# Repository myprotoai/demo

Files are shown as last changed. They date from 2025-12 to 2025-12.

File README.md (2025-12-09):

# ProtoAI

**AI-powered platform that transforms hardware sketches into manufacturable products.**

> **🏆 Hackathon Submission**: [Cursor x Anthropic Hackathon Malaysia](https://luma.com/cursor-hack-my) | [View on Devpost](https://devpost.com/software/protoai-c65x9e)

> **📦 Note**: This repository contains **sample outputs** generated by ProtoAI (assembly instructions, 3D models, PCB files, firmware, etc.), not the ProtoAI platform source code itself.

This repository contains **sample assembly instructions** generated by ProtoAI for building a **Wearable Air Quality Pendant**—a compact, battery-powered device that monitors air quality using TVOC detection with color-coded LED feedback and audio alerts.

### Design Variants

- **Circular Variant** (`samples/circular/`) - Original circular design (32.5mm diameter)
- **Teardrop Variant** (`samples/teardrop/`) - Refined teardrop-shaped design

## 📁 Repository Structure

```
protoai/
├── samples/
│   ├── circular/                    # Circular design variant
│   │   ├── README.md               # Project overview
│   │   ├── Assembly-Instructions.md # Step-by-step assembly guide
│   │   ├── Bill-of-Materials.md    # Complete component list
│   │   ├── 3d-models/               # 3D printable enclosure files
│   │   │   ├── pendant-top-circular.stl
│   │   │   └── pendant-bottom-circular.stl
│   │   ├── firmware/                # Arduino firmware code
│   │   │   └── arduino_code.ino
│   │   ├── pcb/                     # PCB design files
│   │   │   ├── pcb_schematic.pdf
│   │   │   └── gerber_files.zip
│   │   └── images/                  # Assembly instruction images
│   │       ├── 01-pcb-assembly/
│   │       ├── 02-component-installation/
│   │       ├── 03-enclosure-assembly/
│   │       ├── 04-testing/
│   │       └── 05-troubleshooting/
│   │
│   └── teardrop/                    # Teardrop design variant
│       ├── README.md
│       ├── Assembly-Instructions.md
│       ├── Bill-of-Materials.md
│       ├── 3d-models/
│       ├── firmware/
│       ├── pcb/
│       └── images/
│
└── walkthrough.mp4                  # Video demonstration
```

## 🚀 Quick Start

Choose a design variant and follow the assembly guide:
- **Circular** (`samples/circular/`) - 32.5mm diameter
- **Teardrop** (`samples/teardrop/`) - Teardrop-shaped design

Each variant includes PCB files, 3D models (STL), BOM, assembly instructions, and firmware.

## 🔧 Key Features

- **Real-time TVOC monitoring** using SGP40 sensor
- **Ultra-low power design** with STM32U083KCU6 microcontroller
- **Intuitive feedback** - Color-coded LEDs and musical alerts
- **Wearable design** - Compact pendant form factor
- **All-day battery life** with efficient power management
- **USB-C charging** capability

## 📊 Air Quality Classifications

| TVOC Level | Status  | LED Color | Audio Alert |
| --- | --- | --- | --- |
| 0-200 | Good | 🟢 Green | Soft tone |
| 201-300 | Warning | 🟡 Yellow | Warning melody |
| 301-500 | Alarm | 🔴 Red | Urgent beeping |
| >500 | Error | 🔴 Flashing Red | Error tone |

## 🛠️ Hardware Requirements

### Main Components
- **STM32U083KCU6** - Ultra-low-power microcontroller
- **SGP40-D-R4** - Professional TVOC air quality sensor
- **MCP73832T** - Li-Po battery charge controller
- **ADP150AUJZ-2.5-R7** - Low-dropout voltage regulator
- **EAST1616RGBA1** - RGB LEDs (4x)
- **PKMCS0909E4000-R1** - Piezoelectric buzzer

### Tools Required
- Soldering iron and solder
- ST-Link V2 programmer (for firmware upload)
- 3D printer (for enclosure)
- Basic electronics tools

## 📚 Documentation

Each variant includes: README, Assembly Instructions, Bill of Materials, PCB schematic (PDF), and Gerber files. See `walkthrough.mp4` for a video demo.

## 📄 License

MIT

## 🙏 Acknowledgments

This project includes sample assembly instructions and designs based on the [Wearable Air Quality Pendant](https://github.com/Circuit-Digest/Wearable-Air-Quality-Pendant) project by [Circuit-Digest](https://github.com/Circuit-Digest).

### Attribution

Portions of this work are based on:
- **Repository**: [Circuit-Digest/Wearable-Air-Quality-Pendant](https://github.com/Circuit-Digest/Wearable-Air-Quality-Pendant)
- **License**: MIT License
- **Copyright**: © Circuit-Digest

The original project is licensed under the MIT License. The MIT License requires that the above copyright notice and this permission notice be included in all copies or substantial portions of the software.

## 🚀 About ProtoAI

ProtoAI transforms hardware sketches into manufacturable products using AI. Generates 2D diagrams, BOMs, assembly instructions, 3D models (STL), PCB files, and firmware.

**Note**: The ProtoAI platform source code is not included in this repository. This repo contains sample outputs (assembly instructions, 3D models, PCB files, firmware) generated by ProtoAI to demonstrate its capabilities.

**Tech Stack**: Next.js 14, Convex, Tailwind CSS, Radix UI, Zustand

**Team**: [Andre Pratama](https://www.linkedin.com/in/andre-pratama27/), [Hafiz Zakiara](https://www.linkedin.com/in/hafizak/), [Jeremy Yee](https://www.linkedin.com/in/jrmyyee/), [Richard Lee](https://www.linkedin.com/in/yaksheng/)

## 🤝 Contributing

Contributions welcome! For questions, see the `Assembly-Instructions.md` and troubleshooting sections in each variant folder.

---

**⭐ If this project helped you, please consider sharing your build!**

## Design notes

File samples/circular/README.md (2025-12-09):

# Wearable Air Quality Pendant 🌬️
## Circular Casing (Original Design)

A compact, battery-powered wearable device that continuously monitors air quality using TVOC detection. Get real-time feedback about your breathing environment through intuitive LED indicators and audio alerts.

## Project Overview

This DIY air quality monitor pendant uses professional-grade sensors to track Total Volatile Organic Compounds (TVOC) in real-time. Perfect for monitoring indoor air quality at home, office, or industrial environments.

### Key Features

- **Real-time TVOC monitoring** using SGP40 sensor
- **Ultra-low power design** with STM32U083KCU6 microcontroller
- **Intuitive feedback** - Color-coded LEDs and musical alerts
- **Wearable design** - Compact 32.5mm diameter circular pendant
- **All-day battery life** with efficient power management
- **Professional accuracy** with industrial-grade sensor

## Air Quality Classifications

| TVOC Level | Status  | LED Color | Audio Alert |
| --- | --- | --- | --- |
| 0-200 | Good | 🟢 Green | Soft tone |
| 201-300 | Warning | 🟡 Yellow | Warning melody |
| 301-500 | Alarm | 🔴 Red | Urgent beeping |
| >500 | Error | 🔴 Flashing Red | Error tone |

## Hardware Components

### Main Components

- **STM32U083KCU6** - Ultra-low-power microcontroller
- **SGP40-D-R4** - Professional TVOC air quality sensor
- **MCP73832T** - Li-Po battery charge controller
- **ADP150AUJZ-2.5-R7** - Low-dropout voltage regulator
- **EAST1616RGBA1** - RGB LEDs (4x)
- **PKMCS0909E4000-R1** - Piezoelectric buzzer

### Power Management

- Li-Po battery charging via USB-C
- Regulated 2.5V supply for stable operation
- Ultra-low power consumption for all-day use

## 📁 What's in This Package

This ZIP file contains everything you need to build the Air Quality Monitoring Necklace Pendant with **circular casing**:

```
circular/
├── README.md                          # This file - project overview
├── Assembly-Instructions.md           # Step-by-step assembly guide (circular design)
├── Bill-of-Materials.md               # Complete component list with part numbers
├── pcb/
│   ├── pcb_schematic.pdf             # PCB schematic diagram
│   └── gerber_files.zip              # Gerber manufacturing files for PCB fabrication
├── 3d-models/
│   ├── pendant-top-circular.stl      # Top enclosure STL for 3D printing
│   └── pendant-bottom-circular.stl   # Bottom enclosure STL for 3D printing
├── firmware/
│   └── arduino_code.ino              # Arduino firmware code
└── images/
    ├── 01-pcb-assembly/               # 20 PCB assembly instruction images
    ├── 02-component-installation/     # 3 component installation images
    ├── 03-enclosure-assembly/         # 11 enclosure assembly images (circular design)
    ├── 04-testing/                    # 8 testing and verification images
    └── 05-troubleshooting/            # 8 troubleshooting guide images
```

## 🚀 Quick Start Guide

### 1. Hardware Assembly

1. **Order PCB**: Use the Gerber files in `pcb/gerber_files.zip` to order your PCB from a fabrication service
2. **3D Print Enclosure**: Use the STL files in `3d-models/` to print the circular top and bottom enclosure halves
3. **Solder Components**: Follow the detailed `Bill-of-Materials.md` and assembly instructions
4. **Assemble**: Follow the step-by-step guide in `Assembly-Instructions.md`

### 2. Software Setup

1. **Install Arduino IDE** (version 1.8.19 or newer)
2. **Add STM32 board support**
3. **Install required libraries**:
   - DFRobot_SGP40
   - PlayRtttl
   - ptScheduler
4. **Upload firmware**: Use the code in `firmware/arduino_code.ino` with ST-Link programmer

## Required Libraries

Add these libraries through Arduino IDE Library Manager:

```cpp
#include <DFRobot_SGP40.h>     // SGP40 sensor communication
#include <PlayRtttl.hpp>       // Musical tone generation
#include <ptScheduler.h>       // Non-blocking task scheduling
```

## Programming the Device

### Hardware Requirements

- **ST-Link V2 programmer** (required for STM32)
- **USB-C cable** for power and charging
- **3.3V power supply** during programming

### Upload Process

1. Connect ST-Link to SWD pins (SWDIO, SWCLK)
2. Select board: "STM32U0 series" in Arduino IDE
3. Select programmer: "STM32CubeProgrammer (SWD)"
4. Upload firmware

## PCB Specifications

- **Dimensions**: 32.5mm diameter (circular)
- **Layers**: 2-layer PCB
- **Thickness**: 1.6mm
- **Components**: SMD (0603/0402 packages)
- **Connector**: USB-C for charging

## 3D Printing Guide

### Print Settings

- **Layer Height**: 0.2mm
- **Infill**: 20%
- **Supports**: Minimal (only for overhangs)
- **Material**: PLA or PETG recommended

### Post-Processing

- Light sanding for smooth finish
- Ensure USB-C port alignment
- Test fit before final assembly

## Design Variant

This package contains files for the **Circular Casing (Original Design)** variant. The enclosure is a circular shape with a 32.5mm diameter, matching the PCB dimensions.

## Documentation Files

- **Assembly-Instructions.md**: Complete step-by-step guide with images for assembling the circular pendant
- **Bill-of-Materials.md**: Detailed component list with manufacturer part numbers, quantities, and specifications
- **README.md** (this file): Project overview and navigation guide

## Image References

All assembly images are organized in the `images/` folder:
- **PCB Assembly** (`01-pcb-assembly/`): 20 images covering component placement and soldering
- **Component Installation** (`02-component-installation/`): 3 images for battery and final component installation
- **Enclosure Assembly** (`03-enclosure-assembly/`): 11 images specific to the circular enclosure design
- **Testing** (`04-testing/`): 8 images for testing and verification procedures
- **Troubleshooting** (`05-troubleshooting/`): 8 images for common issues and solutions

## Support

- **Assembly Issues**: Refer to the troubleshooting section in `Assembly-Instructions.md`
- **Component Sourcing**: Use the part numbers in `Bill-of-Materials.md` to order from distributors (DigiKey, Mouser, Arrow, etc.)
- **PCB Fabrication**: Use `pcb/gerber_files.zip` with any PCB manufacturer

## Acknowledgments

- **CircuitDigest** - Original project development and documentation
- **DFRobot** - SGP40 sensor library
- **STMicroelectronics** - STM32 microcontroller support

---

**⭐ If this project helped you, please consider sharing your build!**

**📧 Questions?** Refer to the detailed `Assembly-Instructions.md` for step-by-step guidance.

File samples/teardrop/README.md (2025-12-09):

# Wearable Air Quality Pendant 🌬️
## Teardrop Casing (Refined Design)

A compact, battery-powered wearable device that continuously monitors air quality using TVOC detection. Get real-time feedback about your breathing environment through intuitive LED indicators and audio alerts.

## Project Overview

This DIY air quality monitor pendant uses professional-grade sensors to track Total Volatile Organic Compounds (TVOC) in real-time. Perfect for monitoring indoor air quality at home, office, or industrial environments.

### Key Features

- **Real-time TVOC monitoring** using SGP40 sensor
- **Ultra-low power design** with STM32U083KCU6 microcontroller
- **Intuitive feedback** - Color-coded LEDs and musical alerts
- **Wearable design** - Elegant teardrop-shaped pendant (wider at top, tapering to pointed bottom)
- **All-day battery life** with efficient power management
- **Professional accuracy** with industrial-grade sensor

## Air Quality Classifications

| TVOC Level | Status  | LED Color | Audio Alert |
| --- | --- | --- | --- |
| 0-200 | Good | 🟢 Green | Soft tone |
| 201-300 | Warning | 🟡 Yellow | Warning melody |
| 301-500 | Alarm | 🔴 Red | Urgent beeping |
| >500 | Error | 🔴 Flashing Red | Error tone |

## Hardware Components

### Main Components

- **STM32U083KCU6** - Ultra-low-power microcontroller
- **SGP40-D-R4** - Professional TVOC air quality sensor
- **MCP73832T** - Li-Po battery charge controller
- **ADP150AUJZ-2.5-R7** - Low-dropout voltage regulator
- **EAST1616RGBA1** - RGB LEDs (4x)
- **PKMCS0909E4000-R1** - Piezoelectric buzzer

### Power Management

- Li-Po battery charging via USB-C
- Regulated 2.5V supply for stable operation
- Ultra-low power consumption for all-day use

## 📁 What's in This Package

This ZIP file contains everything you need to build the Air Quality Monitoring Necklace Pendant with **teardrop-shaped casing**:

```
teardrop/
├── README.md                          # This file - project overview
├── Assembly-Instructions.md           # Step-by-step assembly guide (teardrop design)
├── Bill-of-Materials.md               # Complete component list with part numbers
├── pcb/
│   ├── pcb_schematic.pdf             # PCB schematic diagram
│   └── gerber_files.zip              # Gerber manufacturing files for PCB fabrication
├── 3d-models/
│   ├── pendant-top-teardrop.stl      # Top enclosure STL for 3D printing (teardrop shape)
│   └── pendant-bottom-teardrop.stl   # Bottom enclosure STL for 3D printing (teardrop shape)
├── firmware/
│   └── arduino_code.ino              # Arduino firmware code
└── images/
    ├── 01-pcb-assembly/               # 20 PCB assembly instruction images (shared with circular)
    ├── 02-component-installation/     # 3 component installation images (shared with circular)
    ├── 03-enclosure-assembly/         # 11 enclosure assembly images (teardrop design)
    ├── 04-testing/                    # 8 testing and verification images (teardrop design)
    └── 05-troubleshooting/            # 8 troubleshooting guide images (teardrop design)
```

## 🚀 Quick Start Guide

### 1. Hardware Assembly

1. **Order PCB**: Use the Gerber files in `pcb/gerber_files.zip` to order your PCB from a fabrication service
2. **3D Print Enclosure**: Use the STL files in `3d-models/` to print the teardrop-shaped top and bottom enclosure halves
3. **Solder Components**: Follow the detailed `Bill-of-Materials.md` and assembly instructions
4. **Assemble**: Follow the step-by-step guide in `Assembly-Instructions.md`

### 2. Software Setup

1. **Install Arduino IDE** (version 1.8.19 or newer)
2. **Add STM32 board support**
3. **Install required libraries**:
   - DFRobot_SGP40
   - PlayRtttl
   - ptScheduler
4. **Upload firmware**: Use the code in `firmware/arduino_code.ino` with ST-Link programmer

## Required Libraries

Add these libraries through Arduino IDE Library Manager:

```cpp
#include <DFRobot_SGP40.h>     // SGP40 sensor communication
#include <PlayRtttl.hpp>       // Musical tone generation
#include <ptScheduler.h>       // Non-blocking task scheduling
```

## Programming the Device

### Hardware Requirements

- **ST-Link V2 programmer** (required for STM32)
- **USB-C cable** for power and charging
- **3.3V power supply** during programming

### Upload Process

1. Connect ST-Link to SWD pins (SWDIO, SWCLK)
2. Select board: "STM32U0 series" in Arduino IDE
3. Select programmer: "STM32CubeProgrammer (SWD)"
4. Upload firmware

## PCB Specifications

- **Dimensions**: 32.5mm diameter (circular PCB, fits within teardrop enclosure)
- **Layers**: 2-layer PCB
- **Thickness**: 1.6mm
- **Components**: SMD (0603/0402 packages)
- **Connector**: USB-C for charging

## 3D Printing Guide

### Print Settings

- **Layer Height**: 0.2mm
- **Infill**: 20%
- **Supports**: Minimal (only for overhangs)
- **Material**: PLA or PETG recommended

### Post-Processing

- Light sanding for smooth finish, especially on curved teardrop surfaces
- Ensure USB-C port alignment (located on side wall, near top wider section)
- Test fit before final assembly
- Verify sensor vent openings are clear

## Design Variant

This package contains files for the **Teardrop Casing (Refined Design)** variant. The enclosure features an elegant teardrop shape:
- **Top Section**: Wider (35-40mm), rounded, bulbous section with attachment loop
- **Middle Section**: Gradual tapering from wide top to narrow bottom
- **Bottom Section**: Tapers to a rounded point (15-20mm minimum width)

**Note**: The PCB remains circular (32.5mm diameter) and fits within the teardrop-shaped enclosure cavity. Only the enclosure shape differs from the original circular design.

## Documentation Files

- **Assembly-Instructions.md**: Complete step-by-step guide with images for assembling the teardrop pendant
- **Bill-of-Materials.md**: Detailed component list with manufacturer part numbers, quantities, and specifications
- **README.md** (this file): Project overview and navigation guide

## Image References

All assembly images are organized in the `images/` folder:
- **PCB Assembly** (`01-pcb-assembly/`): 20 images covering component placement and soldering (same as circular variant - PCB is identical)
- **Component Installation** (`02-component-installation/`): 3 images for battery and final component installation (same as circular variant)
- **Enclosure Assembly** (`03-enclosure-assembly/`): 11 images specific to the teardrop enclosure design (images have `-teardrop.png` suffix)
- **Testing** (`04-testing/`): 8 images for testing and verification procedures with teardrop casing (images have `-teardrop.png` suffix)
- **Troubleshooting** (`05-troubleshooting/`): 8 images for common issues and solutions with teardrop casing (images have `-teardrop.png` suffix)

## Support

- **Assembly Issues**: Refer to the troubleshooting section in `Assembly-Instructions.md`
- **Component Sourcing**: Use the part numbers in `Bill-of-Materials.md` to order from distributors (DigiKey, Mouser, Arrow, etc.)
- **PCB Fabrication**: Use `pcb/gerber_files.zip` with any PCB manufacturer

## Acknowledgments

- **CircuitDigest** - Original project development and documentation
- **DFRobot** - SGP40 sensor library
- **STMicroelectronics** - STM32 microcontroller support

---

**⭐ If this project helped you, please consider sharing your build!**

**📧 Questions?** Refer to the detailed `Assembly-Instructions.md` for step-by-step guidance.

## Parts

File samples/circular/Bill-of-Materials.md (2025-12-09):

# Bill of Materials (BOM)
## Air Quality Monitoring Necklace Pendant

**Project Name:** Air Quality Monitoring Necklace Pendant  
**Document Version:** 1.0  
**Date:** 2025-12-06  
**PCB Revision:** Rev 1.0

---

## Active Components

| Ref | Qty | Manufacturer Part Number | Component Name | Package | Value/Specification | Manufacturer | Category |
|-----|-----|---|---|---|---|---|---|
| U1 | 1 | STM32U083KCU6 | Ultra-low-power 32-bit ARM Cortex-M33 MCU | QFN-48 | 32-bit, 48MHz, 256KB Flash, 32KB RAM | STMicroelectronics | Microcontroller |
| U2 | 1 | SGP40-D-R4 | TVOC Air Quality Sensor | DFN-8 | I2C Interface, 0-60000 ppb range | Sensirion | Sensor |
| U3 | 1 | MCP73832T-2ACI/OT | Li-Po Battery Charge Controller | SOT-23-5 | 4.2V, 500mA max charge current | Microchip Technology | Power Management |
| U4 | 1 | ADP150AUJZ-2.5-R7 | Low-Dropout Voltage Regulator | TSOT-23-5 | 2.5V, 150mA output | Analog Devices | Power Management |

## LEDs and Indicators

| Ref | Qty | Manufacturer Part Number | Component Name | Package | Value/Specification | Manufacturer | Category |
|-----|-----|---|---|---|---|---|---|
| LED1 | 1 | EAST1616RGBA1 | RGB LED | 1.6x1.6mm | Red/Green/Blue, Common Anode | Everlight Electronics | LED |
| LED2 | 1 | EAST1616RGBA1 | RGB LED | 1.6x1.6mm | Red/Green/Blue, Common Anode | Everlight Electronics | LED |
| LED3 | 1 | EAST1616RGBA1 | RGB LED | 1.6x1.6mm | Red/Green/Blue, Common Anode | Everlight Electronics | LED |
| LED4 | 1 | EAST1616RGBA1 | RGB LED | 1.6x1.6mm | Red/Green/Blue, Common Anode | Everlight Electronics | LED |

## Audio Components

| Ref | Qty | Manufacturer Part Number | Component Name | Package | Value/Specification | Manufacturer | Category |
|-----|-----|---|---|---|---|---|---|
| BZ1 | 1 | PKMCS0909E4000-R1 | Piezoelectric Buzzer | 9x9mm | 4kHz, 85dB @ 10cm | Murata Manufacturing | Audio |

## Passive Components - Resistors

| Ref | Qty | Manufacturer Part Number | Component Name | Package | Value/Specification | Manufacturer | Category |
|-----|-----|---|---|---|---|---|---|
| R1 | 1 | RC0603FR-0710KL | Resistor | 0603 | 10kΩ, ±1%, 1/10W | Yageo | Resistor |
| R2 | 1 | RC0603FR-074K7L | Resistor | 0603 | 4.7kΩ, ±1%, 1/10W | Yageo | Resistor |
| R3 | 1 | RC0603FR-072K2L | Resistor | 0603 | 2.2kΩ, ±1%, 1/10W | Yageo | Resistor |
| R4 | 4 | RC0603FR-07100RL | Resistor | 0603 | 100Ω, ±1%, 1/10W | Yageo | Resistor |
| R5 | 4 | RC0603FR-07220RL | Resistor | 0603 | 220Ω, ±1%, 1/10W | Yageo | Resistor |

## Passive Components - Capacitors

| Ref | Qty | Manufacturer Part Number | Component Name | Package | Value/Specification | Manufacturer | Category |
|-----|-----|---|---|---|---|---|---|
| C1 | 1 | CL10A106MQ8NRNC | Ceramic Capacitor | 0805 | 10µF, 25V, X7R | Samsung Electro-Mechanics | Capacitor |
| C2 | 1 | CL10A106MQ8NRNC | Ceramic Capacitor | 0805 | 10µF, 25V, X7R | Samsung Electro-Mechanics | Capacitor |
| C3 | 1 | CL10A475MQ8NRNC | Ceramic Capacitor | 0805 | 4.7µF, 25V, X7R | Samsung Electro-Mechanics | Capacitor |
| C4 | 1 | CL10A104KA8NNNC | Ceramic Capacitor | 0603 | 100nF, 50V, X7R | Samsung Electro-Mechanics | Capacitor |
| C5 | 1 | CL10A104KA8NNNC | Ceramic Capacitor | 0603 | 100nF, 50V, X7R | Samsung Electro-Mechanics | Capacitor |
| C6 | 1 | CL10A104KA8NNNC | Ceramic Capacitor | 0603 | 100nF, 50V, X7R | Samsung Electro-Mechanics | Capacitor |
| C7 | 1 | CL10A104KA8NNNC | Ceramic Capacitor | 0603 | 100nF, 50V, X7R | Samsung Electro-Mechanics | Capacitor |

## Connectors and Interfaces

| Ref | Qty | Manufacturer Part Number | Component Name | Package | Value/Specification | Manufacturer | Category |
|-----|-----|---|---|---|---|---|---|
| J1 | 1 | USB-C-31-M-12 | USB Type-C Connector | Through-hole | USB 2.0, Power/Data | CUI Devices | Connector |
| J2 | 1 | 51021-0200 | Battery Connector | Through-hole | 2-pin JST PH connector | Molex | Connector |
| P1 | 1 | 200-10-104-00-001101 | SWD Programming Header | Through-hole | 4-pin 2.54mm pitch | Preci-Dip | Connector |

## Power Components

| Ref | Qty | Manufacturer Part Number | Component Name | Package | Value/Specification | Manufacturer | Category |
|-----|-----|---|---|---|---|---|---|
| BAT1 | 1 | LP402025 | Lithium Polymer Battery | Custom | 3.7V, 200mAh, 25x20x4mm | Generic | Battery |
| D1 | 1 | BAT54C | Schottky Diode | SOT-23 | 30V, 200mA | Nexperia | Diode |

## Crystals and Oscillators

| Ref | Qty | Manufacturer Part Number | Component Name | Package | Value/Specification | Manufacturer | Category |
|-----|-----|---|---|---|---|---|---|
| Y1 | 1 | ABM8G-32.000MHZ-4Y-T3 | Crystal Oscillator | 3.2x2.5mm | 32MHz, ±20ppm | Abracon | Crystal |

## PCB and Hardware

| Ref | Qty | Manufacturer Part Number | Component Name | Package | Value/Specification | Manufacturer | Category |
|-----|-----|---|---|---|---|---|---|
| PCB1 | 1 | Custom | Printed Circuit Board | 32.5mm diameter | 2-layer, 1.6mm thickness, ENIG finish | Custom Fabrication | PCB |
| SCREW1 | 4 | M1.6x4 | Enclosure Screw | M1.6 | 4mm length, Phillips head | Generic | Hardware |
| SPACER1 | 4 | M1.6x3 | PCB Spacer | M1.6 | 3mm height, threaded | Generic | Hardware |

## Enclosure Components

| Ref | Qty | Manufacturer Part Number | Component Name | Package | Value/Specification | Manufacturer | Category |
|-----|-----|---|---|---|---|---|---|
| ENC1 | 1 | Custom 3D Printed | Pendant Top Enclosure | STL | PLA/PETG, 0.2mm layer height | 3D Printing | Enclosure |
| ENC2 | 1 | Custom 3D Printed | Pendant Bottom Enclosure | STL | PLA/PETG, 0.2mm layer height | 3D Printing | Enclosure |
| CHAIN1 | 1 | Custom | Necklace Chain/Cord | Custom | Adjustable length, breakaway clasp | Generic | Enclosure |

## Miscellaneous

| Ref | Qty | Manufacturer Part Number | Component Name | Package | Value/Specification | Manufacturer | Category |
|-----|-----|---|---|---|---|---|---|
| - | 1 | - | Thermal Pad | Custom | 0.5mm thickness, for sensor mounting | Generic | Thermal Management |
| - | 1 | - | Double-sided Adhesive | Custom | 0.1mm thickness, for battery mounting | Generic | Adhesive |

---

## Component Summary by Category

| Category | Total Quantity |
|---|---|
| Microcontroller | 1 |
| Sensors | 1 |
| Power Management ICs | 2 |
| LEDs | 4 |
| Audio Components | 1 |
| Resistors | 9 |
| Capacitors | 7 |
| Connectors | 3 |
| Battery | 1 |
| Diodes | 1 |
| Crystals | 1 |
| PCB | 1 |
| Hardware (Screws/Spacers) | 8 |
| Enclosure Parts | 3 |
| Miscellaneous | 2 |

**Total Component Count:** 45 unique components  
**Total Part Count:** 49 parts (including multiples)

---

## Notes

1. **Component Sourcing**: All components listed use industry-standard part numbers and are available through major distributors (DigiKey, Mouser, Arrow, etc.)

2. **PCB Specifications**: 
   - 2-layer PCB design
   - 32.5mm diameter circular board
   - 1.6mm board thickness
   - ENIG (Electroless Nickel Immersion Gold) surface finish
   - Minimum trace width: 0.1mm
   - Minimum via size: 0.2mm

3. **Battery Specifications**:
   - Lithium Polymer (Li-Po) battery
   - Nominal voltage: 3.7V
   - Capacity: 200mAh minimum
   - Dimensions: 25mm x 20mm x 4mm (or similar compact form factor)
   - Must include built-in protection circuit

4. **Enclosure Specifications**:
   - 3D printed from PLA or PETG material
   - Layer height: 0.2mm recommended
   - Infill: 20% minimum
   - Post-processing: Light sanding for smooth finish
   - Must provide ventilation for sensor air sampling

5. **Assembly Considerations**:
   - All SMD components are hand-solderable with appropriate tools
   - Use lead-free solder (RoHS compliant)
   - Follow ESD precautions during assembly
   - Verify component orientation before soldering

6. **Regulatory Compliance**:
   - Components should be RoHS compliant
   - Battery must meet UN38.3 transportation requirements
   - Consider CE/FCC compliance for final product

---

**Document Control:**
- Prepared by: ProtoAI Design System
- Reviewed by: [To be assigned]
- Approved by: [To be assigned]
- Next Review Date: [To be determined]

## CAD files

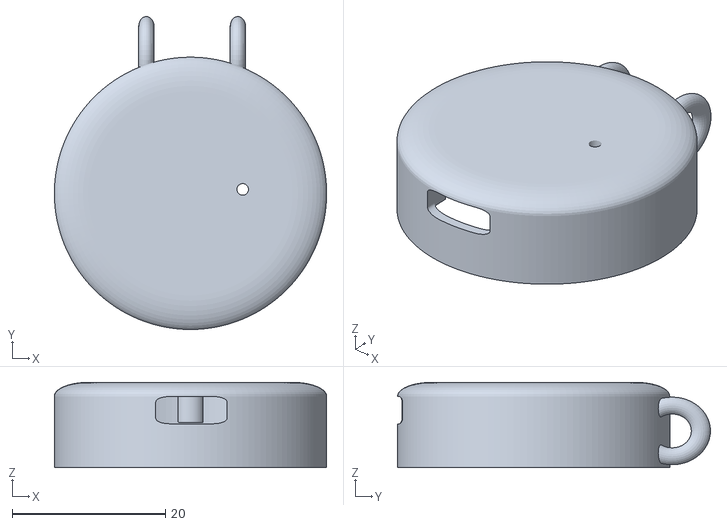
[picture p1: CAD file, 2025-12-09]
samples/circular/3d-models/pendant-top-circular.stl
35.5 x 40.8 x 11.1

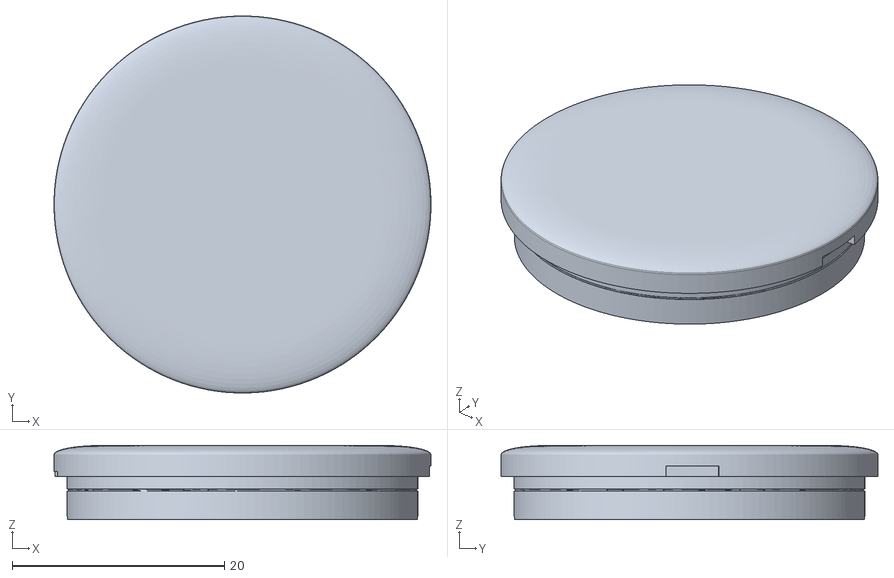
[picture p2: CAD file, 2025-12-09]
samples/circular/3d-models/pendant-bottom-circular.stl
35.5 x 35.5 x 6.97

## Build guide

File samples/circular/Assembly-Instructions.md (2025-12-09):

# Assembly Instructions
## Air Quality Monitoring Necklace Pendant - Circular Casing (Original Design)

**Project Name:** Air Quality Monitoring Necklace Pendant (Circular Casing - Original Design)  
**Document Version:** 1.0  
**Date:** 2025-12-06  
**Design Variant:** Original (Circular) - Generated from initial design prompt  
**Estimated Assembly Time:** 2-3 hours  
**Difficulty Level:** Intermediate (requires basic soldering skills)

---

## Table of Contents

1. [Introduction](#introduction)
2. [Safety Precautions](#safety-precautions)
3. [Required Tools and Equipment](#required-tools-and-equipment)
4. [Pre-Assembly Checklist](#pre-assembly-checklist)
5. [PCB Assembly](#pcb-assembly)
6. [Component Installation](#component-installation)
7. [Enclosure Assembly](#enclosure-assembly)
8. [Testing and Calibration](#testing-and-calibration)
9. [Troubleshooting](#troubleshooting)
10. [Final Verification](#final-verification)

---

## Introduction

This document provides step-by-step instructions for assembling the Air Quality Monitoring Necklace Pendant. The device is a compact, wearable pendant that monitors air quality using a TVOC sensor and provides visual feedback through RGB LEDs.

### Device Overview

The pendant consists of:
- **Main PCB**: 32.5mm diameter circular board with all electronic components
- **Enclosure**: 3D printed top and bottom halves
- **Battery**: Rechargeable Li-Po battery (200mAh, 3.7V)
- **Necklace Chain**: Adjustable chain or cord with breakaway clasp

### Key Features

- Real-time TVOC (Total Volatile Organic Compounds) monitoring
- Color-coded LED feedback (Green/Yellow/Red)
- Audio alerts via piezoelectric buzzer
- USB-C charging capability
- All-day battery life (16+ hours)

---

## Safety Precautions

⚠️ **IMPORTANT: Read all safety precautions before beginning assembly**

1. **ESD Protection**: Always use an anti-static mat and wrist strap when handling components. Static electricity can damage sensitive ICs.

2. **Soldering Safety**:
   - Work in a well-ventilated area
   - Use safety glasses to protect eyes from solder splashes
   - Keep soldering iron in a secure holder when not in use
   - Allow components to cool before handling

3. **Battery Safety**:
   - Never short-circuit the battery terminals
   - Do not puncture, crush, or expose battery to extreme heat
   - Use only the specified battery type and capacity
   - Charge battery only when properly installed in device

4. **Chemical Safety**:
   - Avoid inhaling flux fumes during soldering
   - Wash hands after handling solder and flux
   - Keep cleaning solvents away from heat sources

5. **General Safety**:
   - Disconnect power before making any modifications
   - Double-check component orientation before soldering
   - Verify polarity of all polarized components

---

## Required Tools and Equipment

### Essential Tools

| Tool | Specification | Purpose |
|---|---|---|
| Soldering Iron | 30-40W, adjustable temperature (300-400°C) | Component soldering |
| Solder | Lead-free, 0.5-0.8mm diameter, rosin core | Electrical connections |
| Solder Wick | 2-3mm width | Desoldering and cleanup |
| Flux | Rosin-based, no-clean | Improved solder flow |
| Tweezers | ESD-safe, fine tip | Component placement |
| Wire Cutters | Flush cut | Lead trimming |
| Multimeter | Digital, basic functions | Continuity and voltage testing |
| Magnifying Glass | 3-5x magnification | Inspection of small components |
| Anti-static Mat | ESD-safe workspace | Static protection |
| Anti-static Wrist Strap | ESD-safe | Personal static protection |

### Optional but Recommended

- Hot air rework station (for SMD components)
- Solder paste stencil (for batch assembly)
- Component organizer trays
- Helping hands tool
- Isopropyl alcohol and lint-free wipes (for cleaning)

### Software Tools

- ST-Link V2 programmer (for firmware upload)
- USB-C cable (for charging and programming)
- Arduino IDE or STM32CubeIDE (for firmware development)

---

## Pre-Assembly Checklist

Before beginning assembly, verify you have all required components:

### Component Verification

- [ ] PCB received and inspected for damage
- [ ] All components from BOM verified and organized
- [ ] 3D printed enclosure parts received (top and bottom)
- [ ] Battery received and checked for damage
- [ ] Necklace chain/cord received
- [ ] All tools available and in working condition

### Workspace Setup

- [ ] Clean, well-lit workspace prepared
- [ ] Anti-static mat laid out
- [ ] Anti-static wrist strap ready
- [ ] Soldering station set up and tested
- [ ] Component organizer trays labeled
- [ ] Safety equipment (glasses, ventilation) ready

### PCB Inspection

1. **Visual Inspection**:
   - Check PCB for scratches, cracks, or delamination
   - Verify all pads are clean and free of oxidation
   - Check for any manufacturing defects
   - Verify silkscreen labels are clear and readable

2. **Continuity Check**:
   - Use multimeter to verify no short circuits between power and ground
   - Check for any obvious manufacturing errors

---

## PCB Assembly

### Step 1: Prepare Workspace

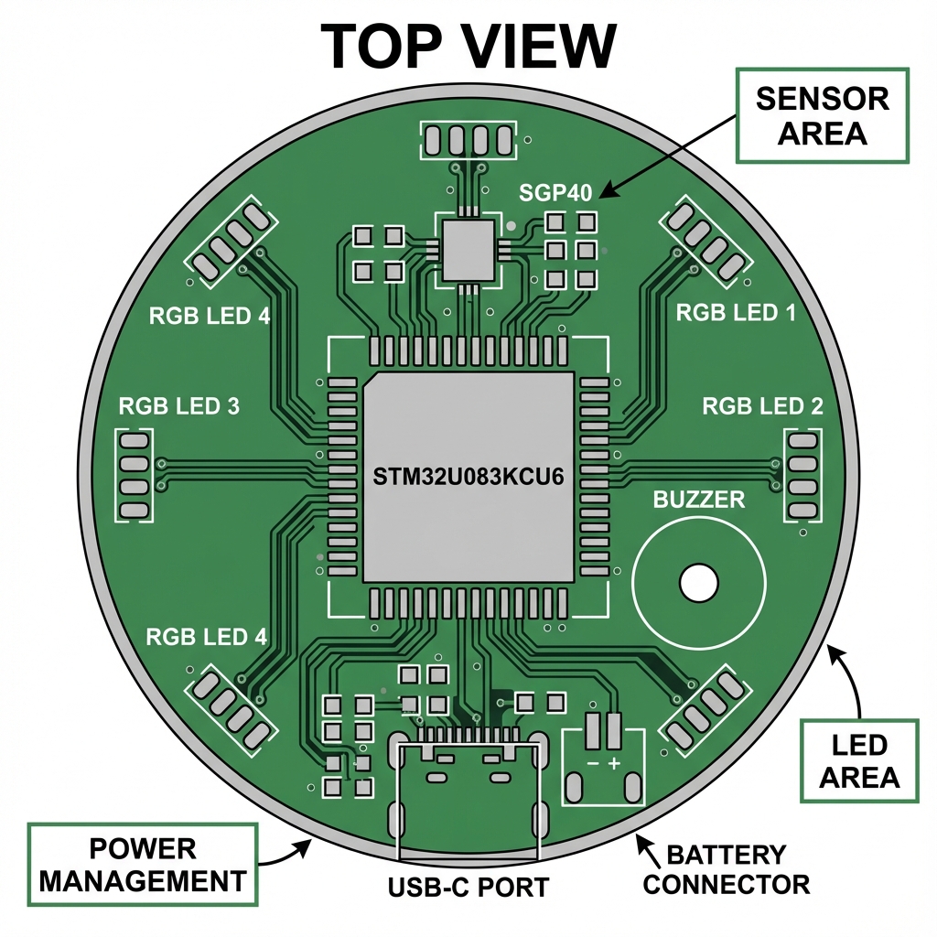
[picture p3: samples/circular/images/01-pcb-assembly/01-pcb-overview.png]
PCB Overview


1. Put on anti-static wrist strap and connect to ground
2. Place PCB on anti-static mat
3. Organize components by package size for easy access
4. Set soldering iron to appropriate temperature (350°C for lead-free solder)

**Reference**: See PCB overview image above for component locations.

### Step 2: Install Passive Components (Resistors and Capacitors)

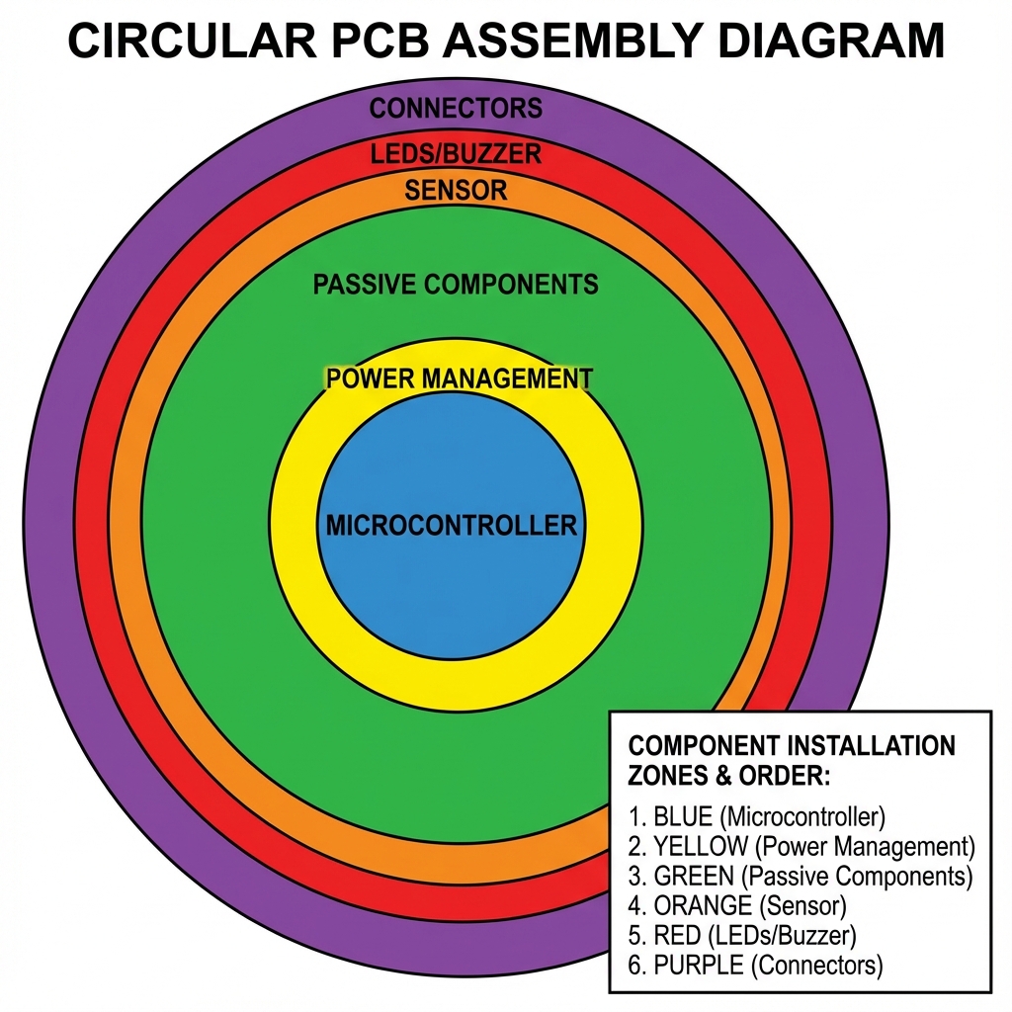
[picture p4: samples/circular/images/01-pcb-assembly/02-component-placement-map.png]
Component Placement Map


**Order of Installation**: Start with smallest components and work up to larger ones. Follow the color-coded installation sequence shown in the component placement map above.

#### 2.1 Install Resistors (R1-R5)

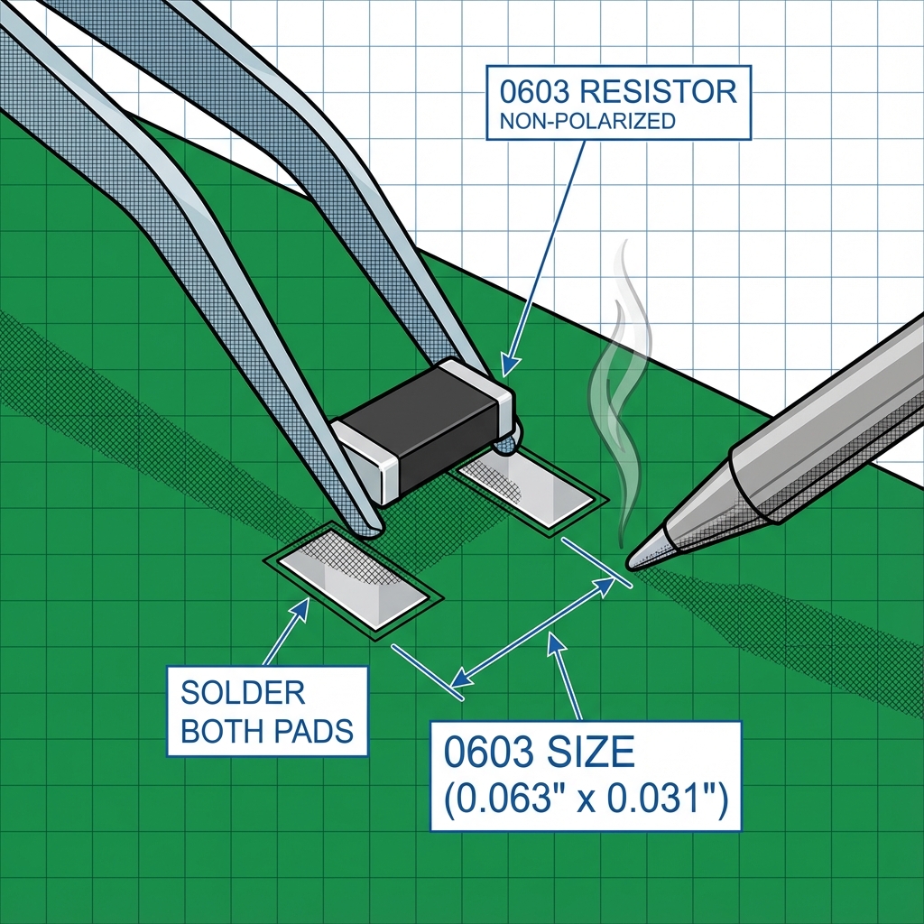
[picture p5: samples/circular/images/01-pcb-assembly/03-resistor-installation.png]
Resistor Installation


1. **R1 (10kΩ)**:
   - Locate R1 position on PCB (check silkscreen)
   - Verify resistor value using multimeter (should read ~10kΩ)
   - Place resistor on PCB pads
   - Verify orientation (resistors are non-polarized)
   - Solder one pad, check alignment, then solder second pad
   - Trim excess leads flush to board

2. **R2 (4.7kΩ)**:
   - Repeat process for R2
   - Verify value: ~4.7kΩ

3. **R3 (2.2kΩ)**:
   - Repeat process for R3
   - Verify value: ~2.2kΩ

4. **R4 (100Ω, 4x)**:
   - Install all four R4 resistors
   - Verify value: ~100Ω each

5. **R5 (220Ω, 4x)**:
   - Install all four R5 resistors
   - Verify value: ~220Ω each

**Verification**: Use multimeter to check each resistor value after installation.

#### 2.2 Install Capacitors (C1-C7)

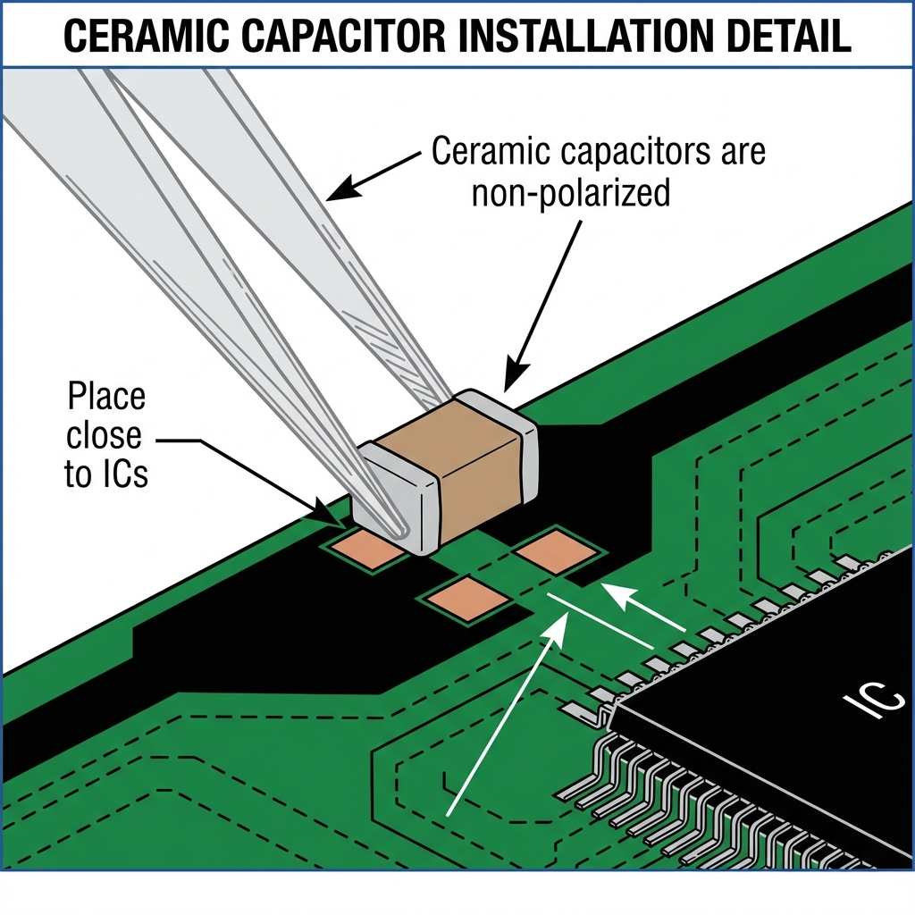
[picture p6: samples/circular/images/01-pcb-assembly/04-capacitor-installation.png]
Capacitor Installation


1. **C1, C2 (10µF)**:
   - Locate C1 and C2 positions
   - **IMPORTANT**: Ceramic capacitors are non-polarized
   - Place capacitors on pads
   - Solder both pads
   - Trim excess leads

2. **C3 (4.7µF)**:
   - Install C3 using same process

3. **C4-C7 (100nF, 4x)**:
   - Install all four 100nF capacitors
   - These are decoupling capacitors - ensure they're close to their respective ICs

**Verification**: Check for proper solder joints and no bridges between pads.

### Step 3: Install Power Management Components

#### 3.1 Install Voltage Regulator (U4 - ADP150)

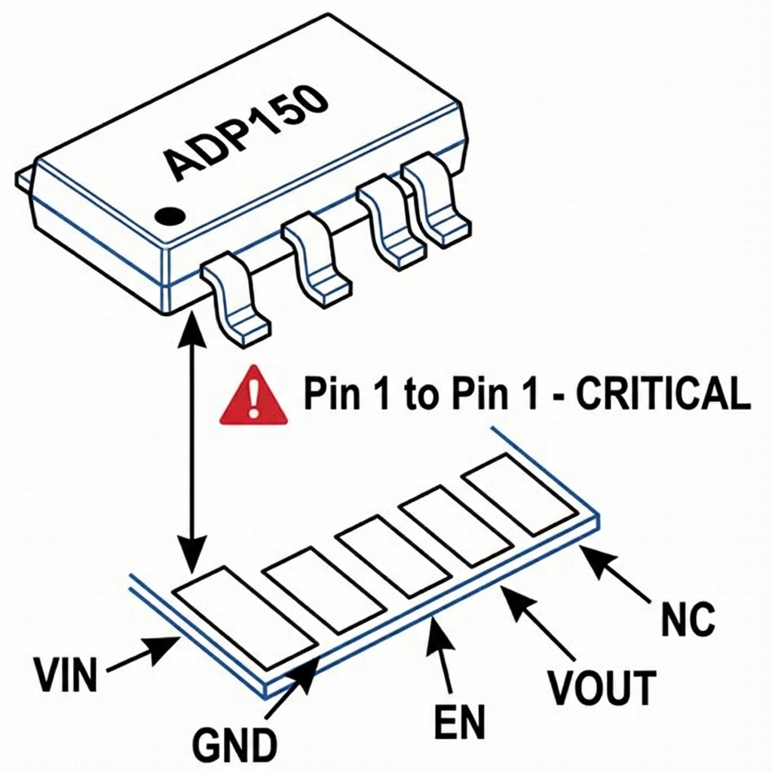
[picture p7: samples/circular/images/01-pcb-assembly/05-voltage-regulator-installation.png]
Voltage Regulator Installation


1. **Identify Pin 1**:
   - Locate pin 1 indicator on IC (usually a dot or notch)
   - Match with pin 1 indicator on PCB silkscreen

2. **Placement**:
   - Apply small amount of flux to pads
   - Place IC on pads, ensuring pin 1 alignment
   - Verify all pins are on their respective pads

3. **Soldering**:
   - For TSOT-23 package, use fine-tip soldering iron
   - Solder pin 1 first to secure position
   - Solder remaining pins carefully
   - Check for solder bridges between pins
   - Use solder wick to remove any bridges

**Verification**: 
- Check continuity between pins and pads
- Verify no short circuits between adjacent pins

#### 3.2 Install Battery Charge Controller (U3 - MCP73832)

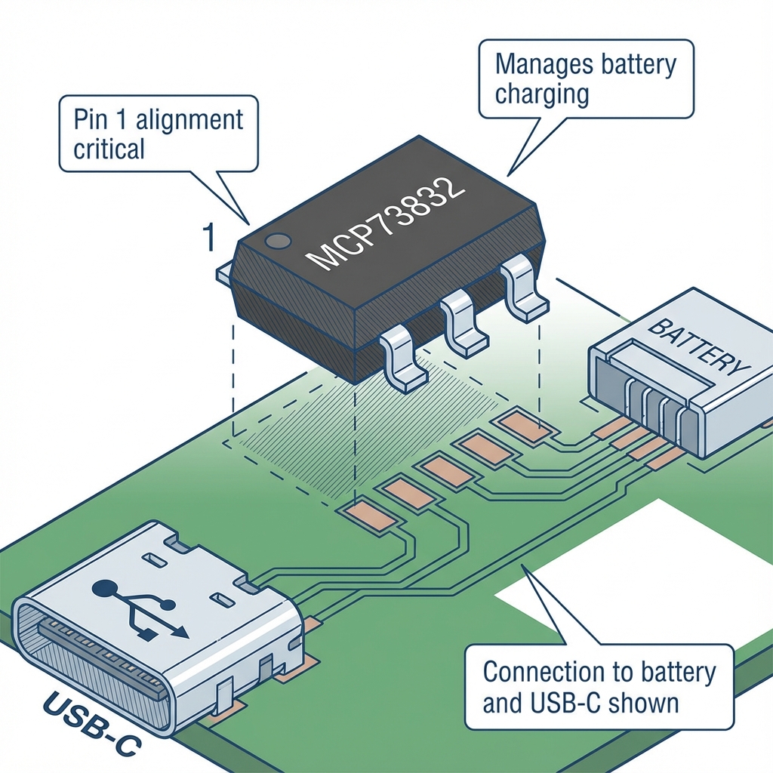
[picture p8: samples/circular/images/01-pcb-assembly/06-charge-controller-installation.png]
Charge Controller Installation


1. Follow same process as U4
2. **Critical**: Ensure correct orientation (pin 1 to pin 1)
3. This IC manages battery charging - incorrect installation will prevent charging

**Verification**: Check pin alignment and solder quality.

#### 3.3 Install Schottky Diode (D1)

**Note**: Diode orientation is critical. Match the cathode stripe (marked on diode) with the silkscreen marking on PCB.

1. **Identify Cathode**:
   - Diode has a stripe on cathode end
   - Match cathode stripe with silkscreen marking on PCB

2. **Placement and Soldering**:
   - Place diode with correct orientation
   - Solder both pads
   - **WARNING**: Reversed polarity will damage circuit

**Verification**: Check orientation matches silkscreen.

### Step 4: Install Microcontroller (U1 - STM32U083KCU6)

⚠️ **CRITICAL STEP**: This is the most important component. Take extra care.

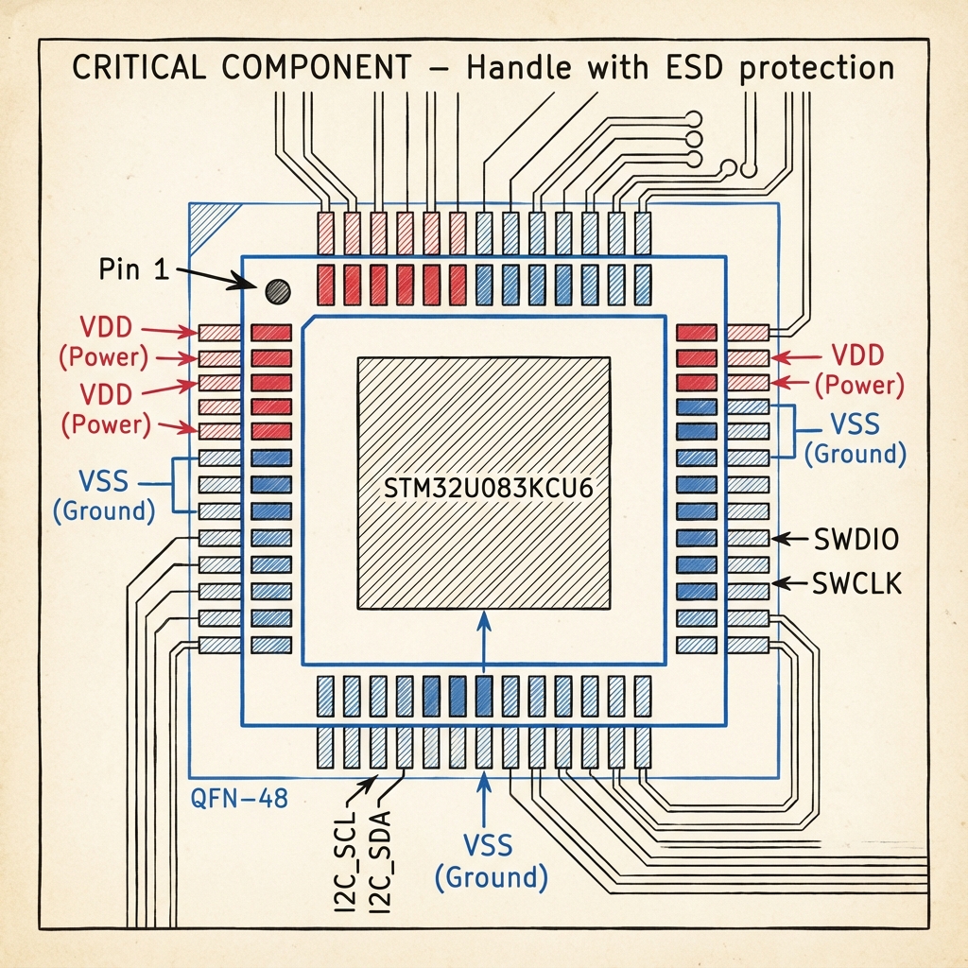
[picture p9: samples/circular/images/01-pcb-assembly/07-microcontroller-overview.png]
Microcontroller Overview


1. **Preparation**:
   - Verify microcontroller part number matches BOM
   - Check for any bent pins
   - Clean pads on PCB with isopropyl alcohol

2. **Pin 1 Identification**:
   - Locate pin 1 indicator on IC (usually a dot in corner)
   - Match with pin 1 indicator on PCB (usually a square pad or dot)

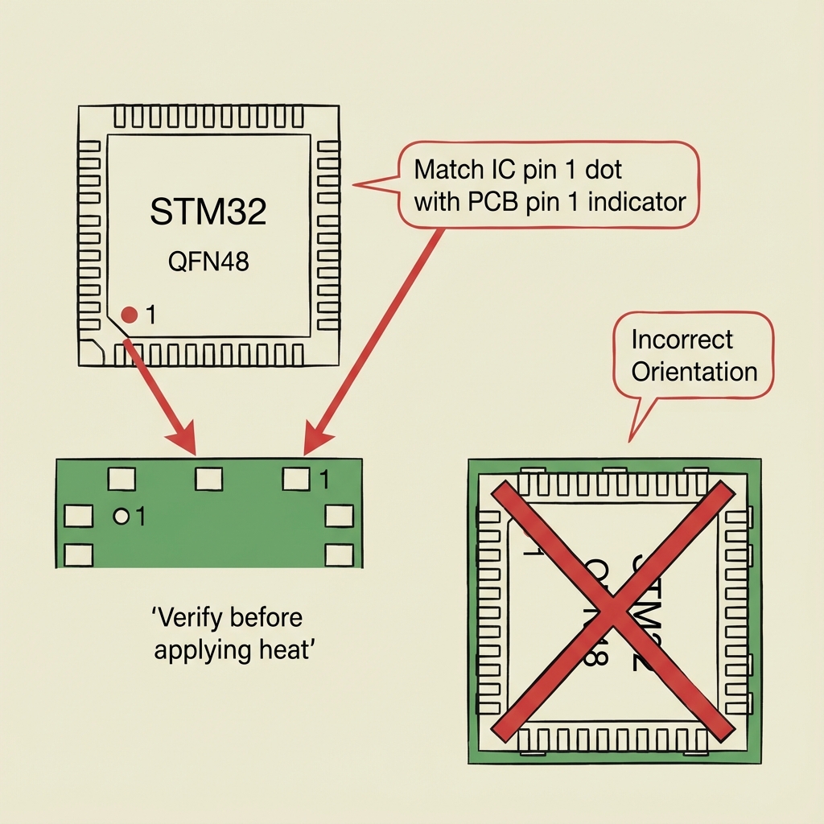
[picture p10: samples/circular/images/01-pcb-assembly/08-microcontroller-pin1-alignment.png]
Pin 1 Alignment


3. **Placement**:
   - For QFN-48 package, alignment is critical
   - Apply flux to PCB pads
   - Carefully place IC, ensuring pin 1 alignment
   - Verify all pads are visible around IC perimeter

4. **Soldering**:
   - **Method 1 (Hot Air)**:
     - Use hot air rework station
     - Apply heat evenly around IC (350°C, low airflow)
     - Watch for solder to flow and IC to "settle"
     - Allow to cool before moving
   
   - **Method 2 (Soldering Iron)**:
     - Solder corner pins first to secure position
     - Apply flux to all pads
     - Drag solder technique: apply solder to iron tip, drag across pins
     - Use solder wick to remove excess and bridges
     - Check each pin for proper connection

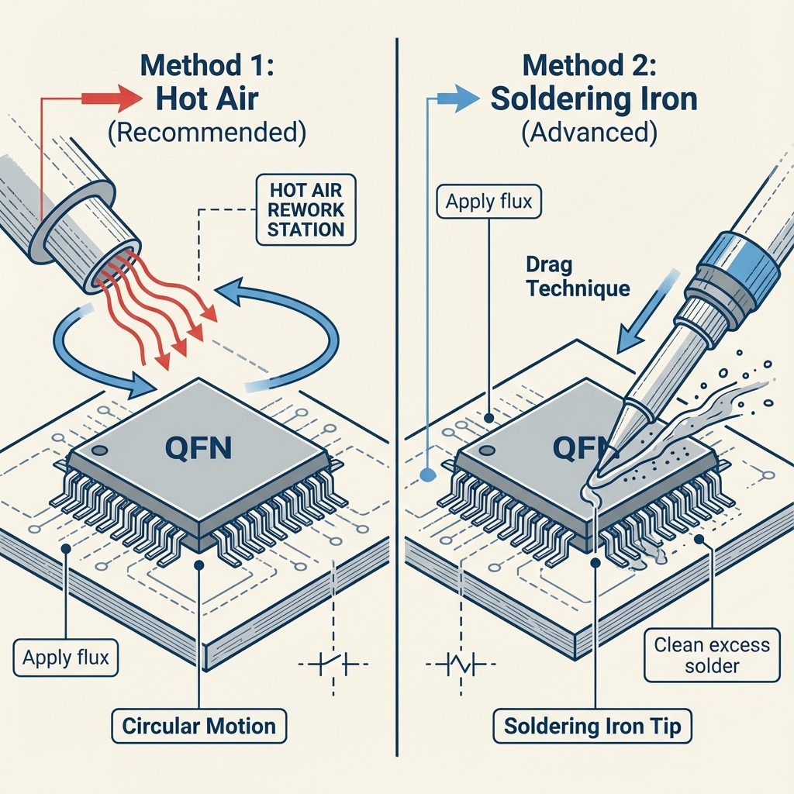
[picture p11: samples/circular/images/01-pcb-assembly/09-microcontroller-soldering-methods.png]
Soldering Methods


5. **Verification**:
   - Inspect all pins under magnification
   - Check for solder bridges
   - Verify no cold solder joints
   - Test continuity between adjacent pins (should be open circuit)

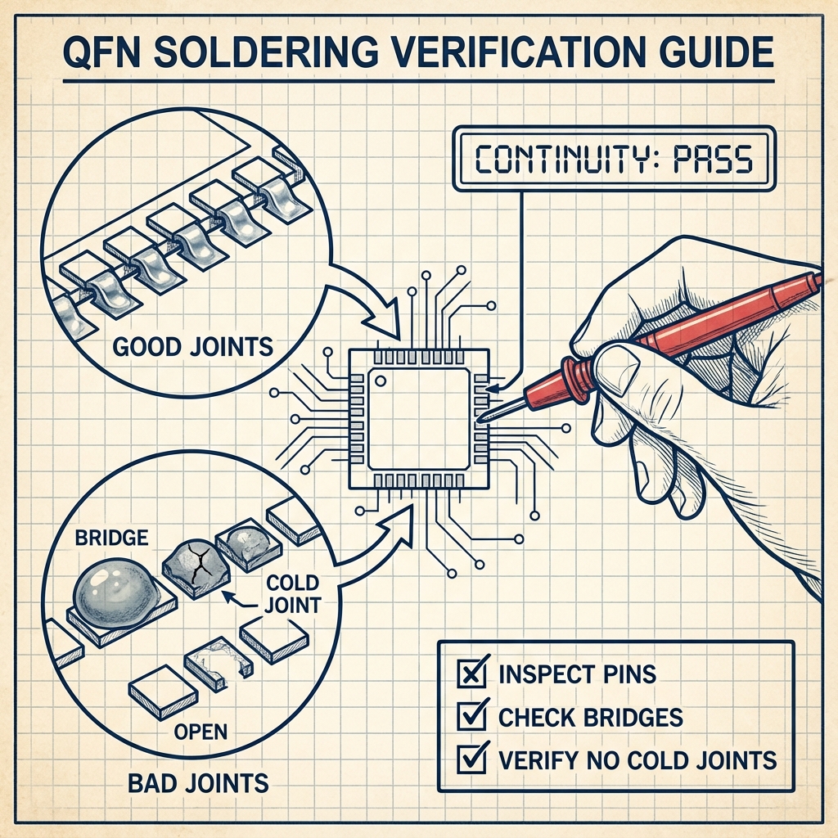
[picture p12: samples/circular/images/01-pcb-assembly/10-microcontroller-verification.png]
Microcontroller Verification


### Step 5: Install Air Quality Sensor (U2 - SGP40)

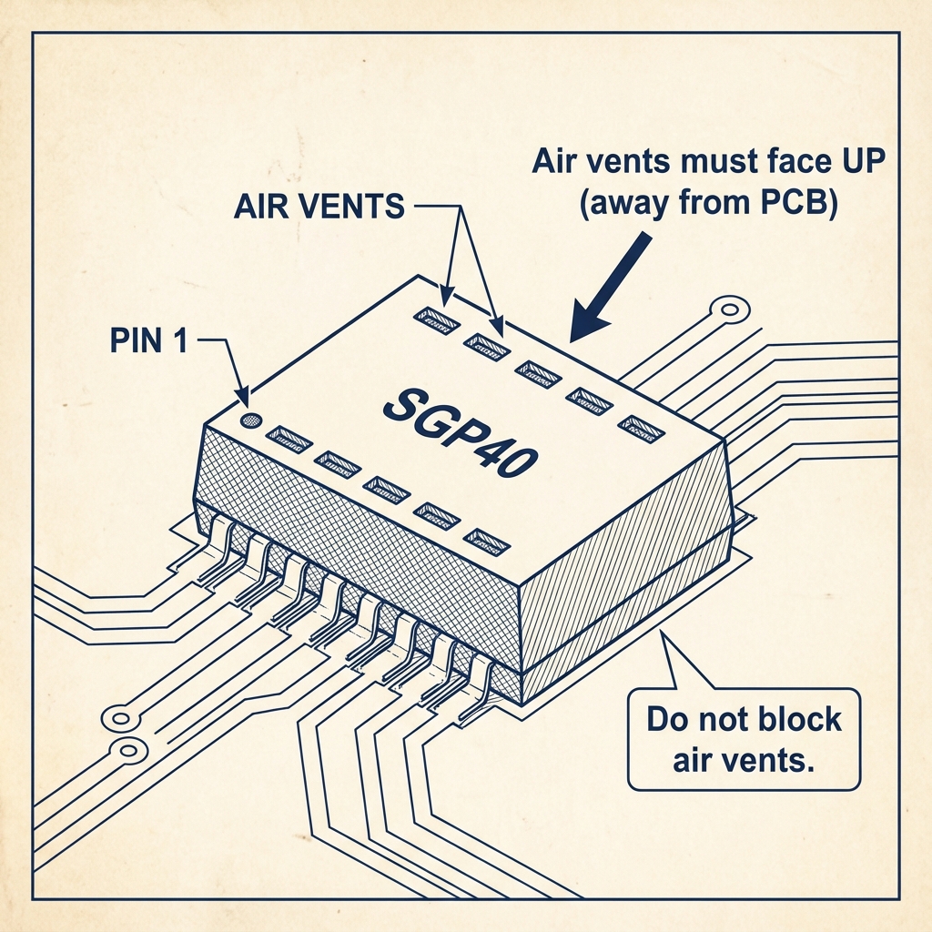
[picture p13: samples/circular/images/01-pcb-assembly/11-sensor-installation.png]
Sensor Installation


1. **Sensor Orientation**:
   - SGP40 has air sampling vents on top
   - Ensure vents face upward (away from PCB) when installed
   - Match pin 1 with PCB pin 1 indicator

2. **Placement**:
   - Apply thermal pad to sensor bottom (if specified)
   - Place sensor on PCB pads
   - Verify air vents are not blocked

3. **Soldering**:
   - Use fine-tip soldering iron
   - Solder all 8 pins carefully
   - **IMPORTANT**: Do not overheat sensor - it contains sensitive sensing elements

4. **Air Vent Clearance**:
   - Verify sensor vents have clearance above PCB
   - Ensure enclosure will not block air flow to sensor

**Verification**: 
- Check sensor is properly seated
- Verify air vents are accessible
- Test I2C communication (requires firmware)

### Step 6: Install RGB LEDs (LED1-LED4)

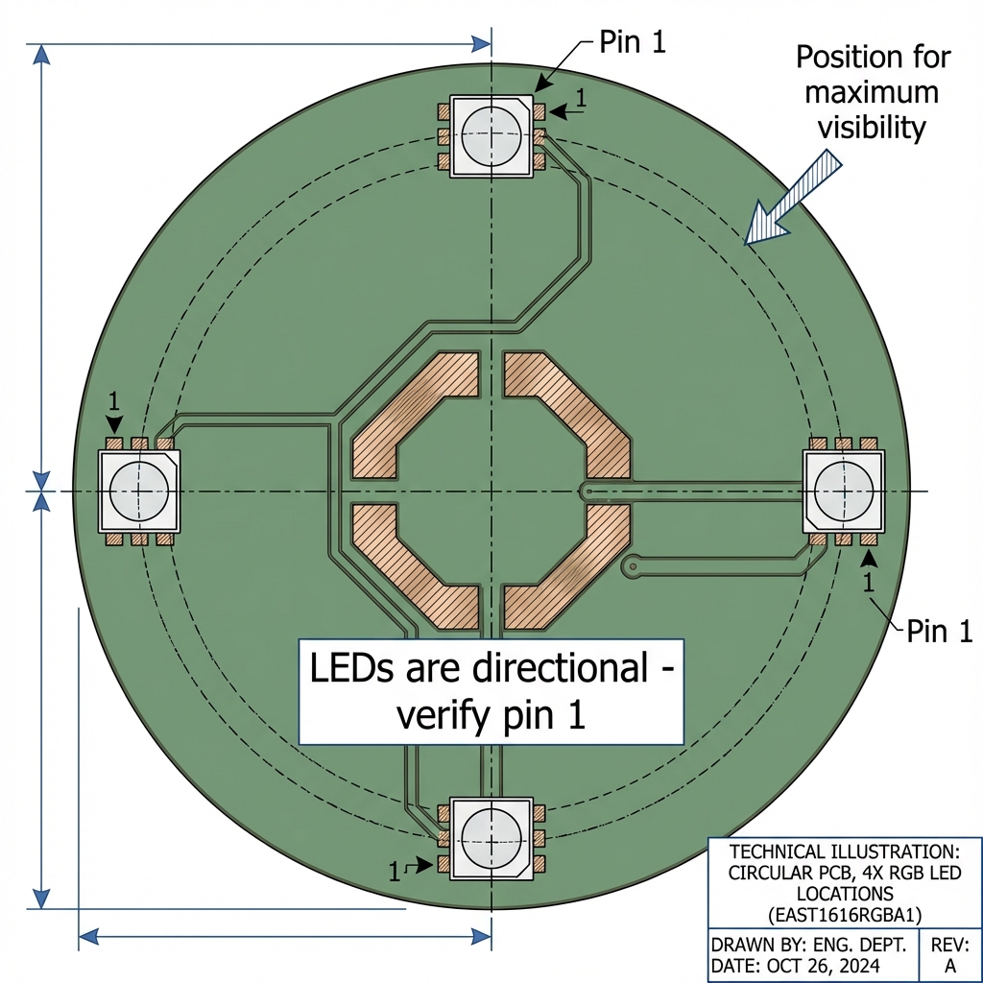
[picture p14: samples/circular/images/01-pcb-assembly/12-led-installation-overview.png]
LED Installation Overview


1. **LED Identification**:
   - EAST1616RGBA1 LEDs have 4 pins (R, G, B, Common Anode)
   - Identify pin 1 (usually marked with dot or different pad shape)
   - Match with PCB silkscreen

2. **Installation Process** (repeat for all 4 LEDs):
   - Place LED on PCB pads
   - Verify pin 1 alignment
   - Solder all 4 pins
   - **IMPORTANT**: LEDs are directional - incorrect orientation will prevent operation

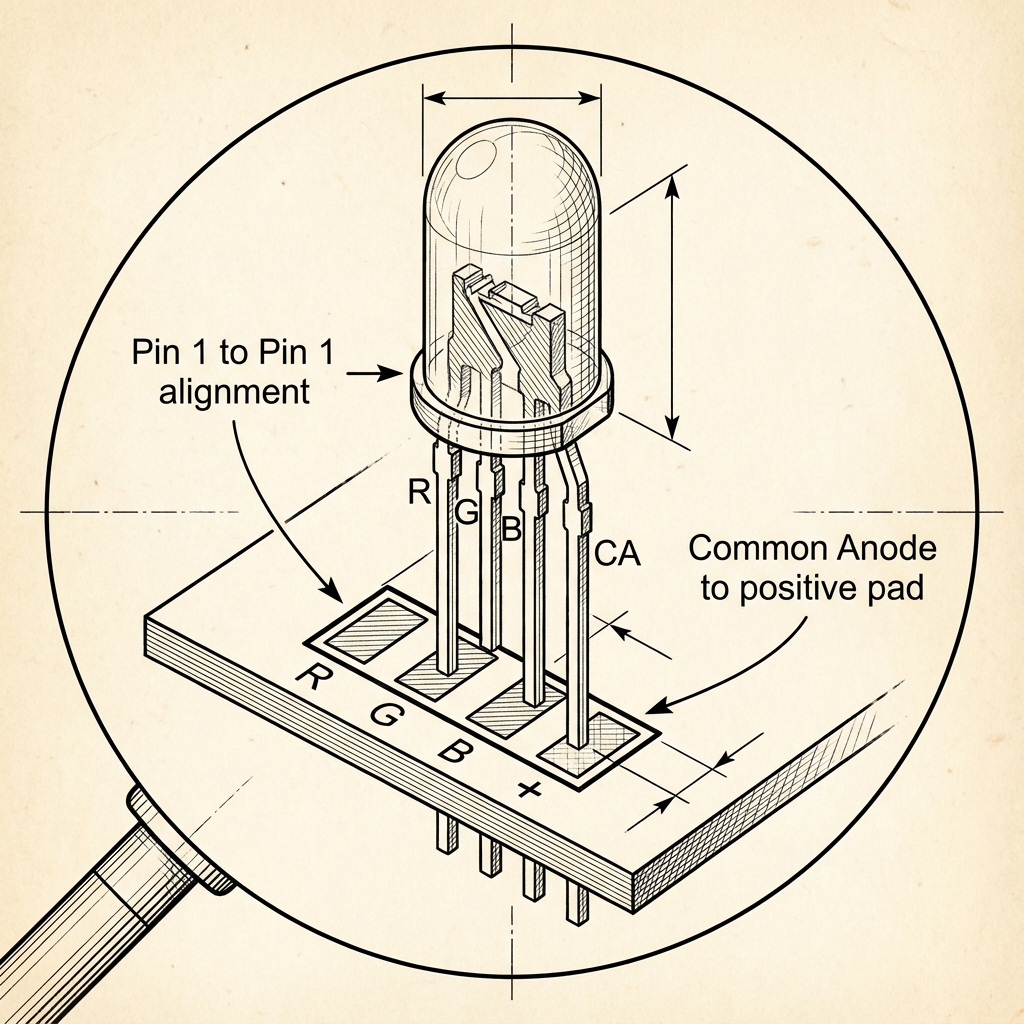
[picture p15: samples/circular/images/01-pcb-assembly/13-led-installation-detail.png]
LED Installation Detail


3. **LED Placement**:
   - LEDs should be positioned to maximize visibility through enclosure
   - Ensure LEDs are flush with PCB surface
   - Check that LED lenses are not scratched

**Verification**: 
- Visual inspection of all LED installations
- Verify pin alignment matches silkscreen
- Test LEDs after power-up (requires firmware)

### Step 7: Install Piezoelectric Buzzer (BZ1)

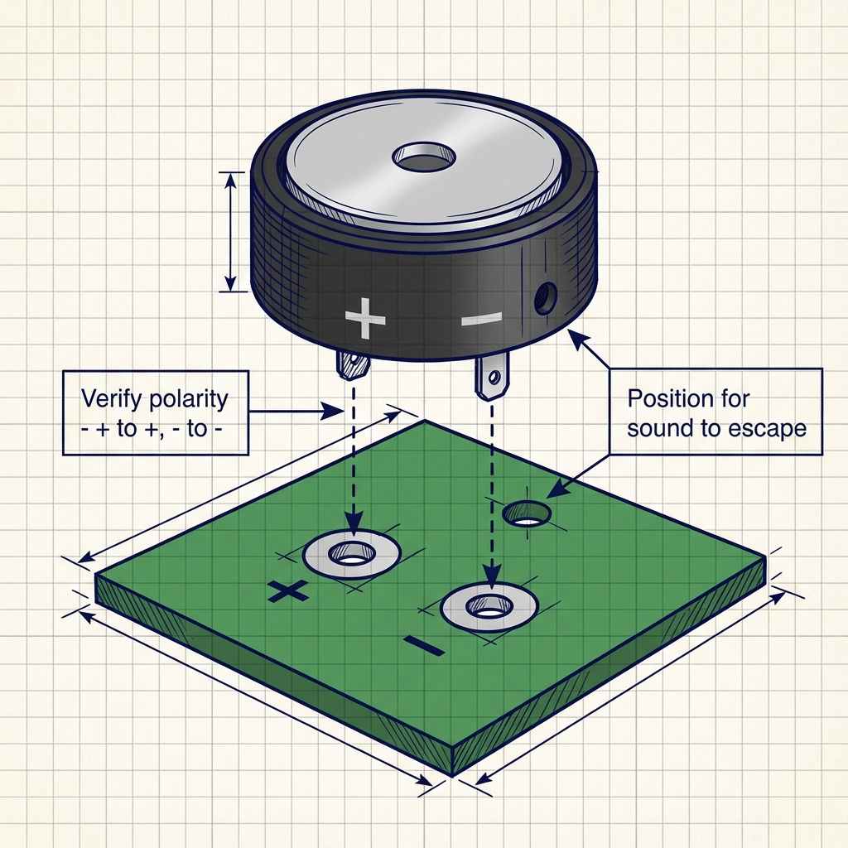
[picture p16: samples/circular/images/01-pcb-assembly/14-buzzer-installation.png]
Buzzer Installation


1. **Buzzer Orientation**:
   - Piezoelectric buzzers are polarized
   - Identify positive (+) and negative (-) terminals
   - Match with PCB markings

2. **Placement**:
   - Place buzzer on PCB pads
   - Ensure correct polarity
   - Buzzer should be positioned to allow sound to escape enclosure

3. **Soldering**:
   - Solder both terminals
   - Verify secure mechanical connection

**Verification**: Check polarity and secure mounting.

### Step 8: Install Crystal Oscillator (Y1)

**Note**: Crystals are non-polarized. Place on PCB pads and solder both terminals.

1. **Crystal Installation**:
   - Crystals are non-polarized
   - Place crystal on PCB pads
   - Solder both terminals
   - Keep leads as short as possible

2. **Mounting Considerations**:
   - Crystal should be close to microcontroller
   - Avoid mechanical stress on crystal

**Verification**: Check solder joints and positioning.

### Step 9: Install Connectors

#### 9.1 USB Type-C Connector (J1)

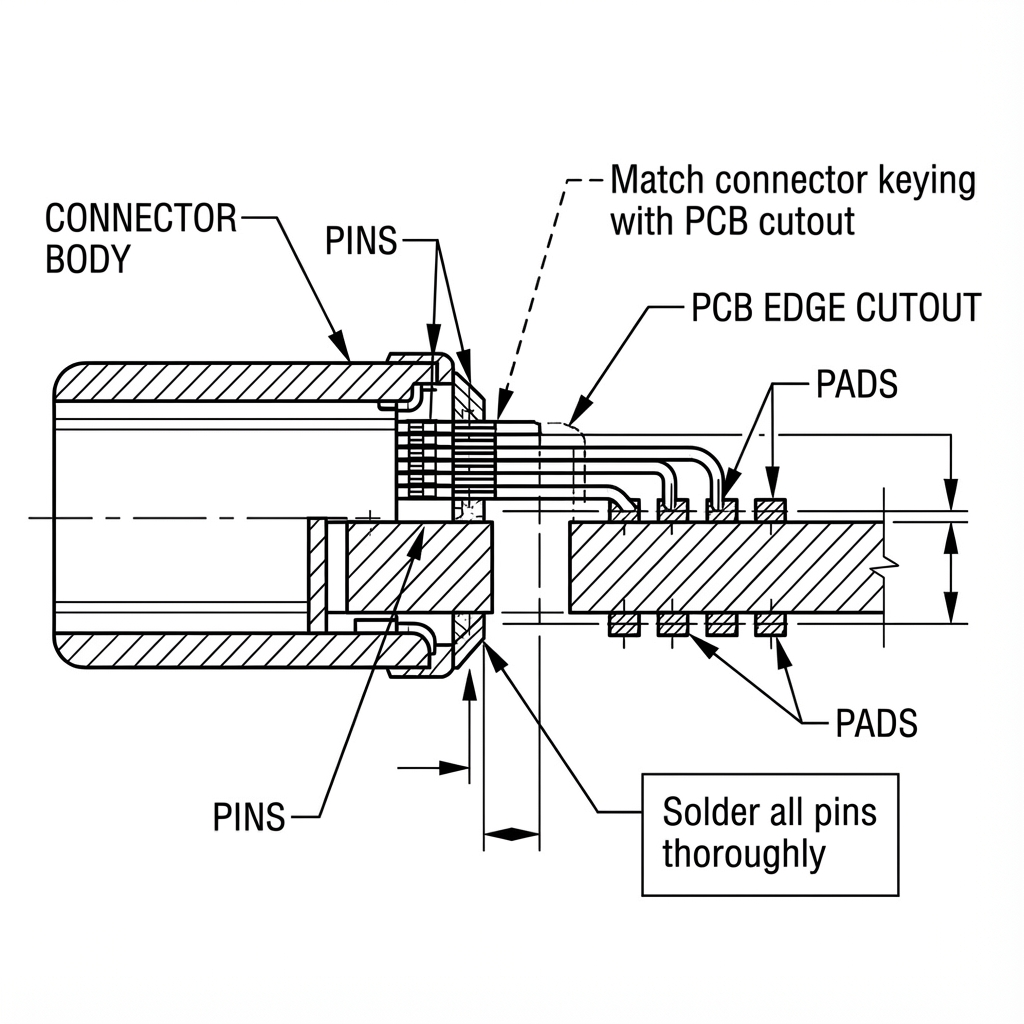
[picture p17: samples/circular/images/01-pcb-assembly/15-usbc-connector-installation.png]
USB-C Connector Installation


1. **Connector Orientation**:
   - USB-C connectors have specific mounting orientation
   - Match connector keying with PCB cutout
   - Verify connector will align with enclosure opening

2. **Placement and Soldering**:
   - Insert connector into PCB from top side
   - Solder all pins (USB-C has many pins - be thorough)
   - Verify connector is flush with PCB surface
   - Check for proper mechanical retention

**Verification**: 
- Verify connector alignment with enclosure
- Test connector retention (should not wobble)

#### 9.2 Battery Connector (J2)

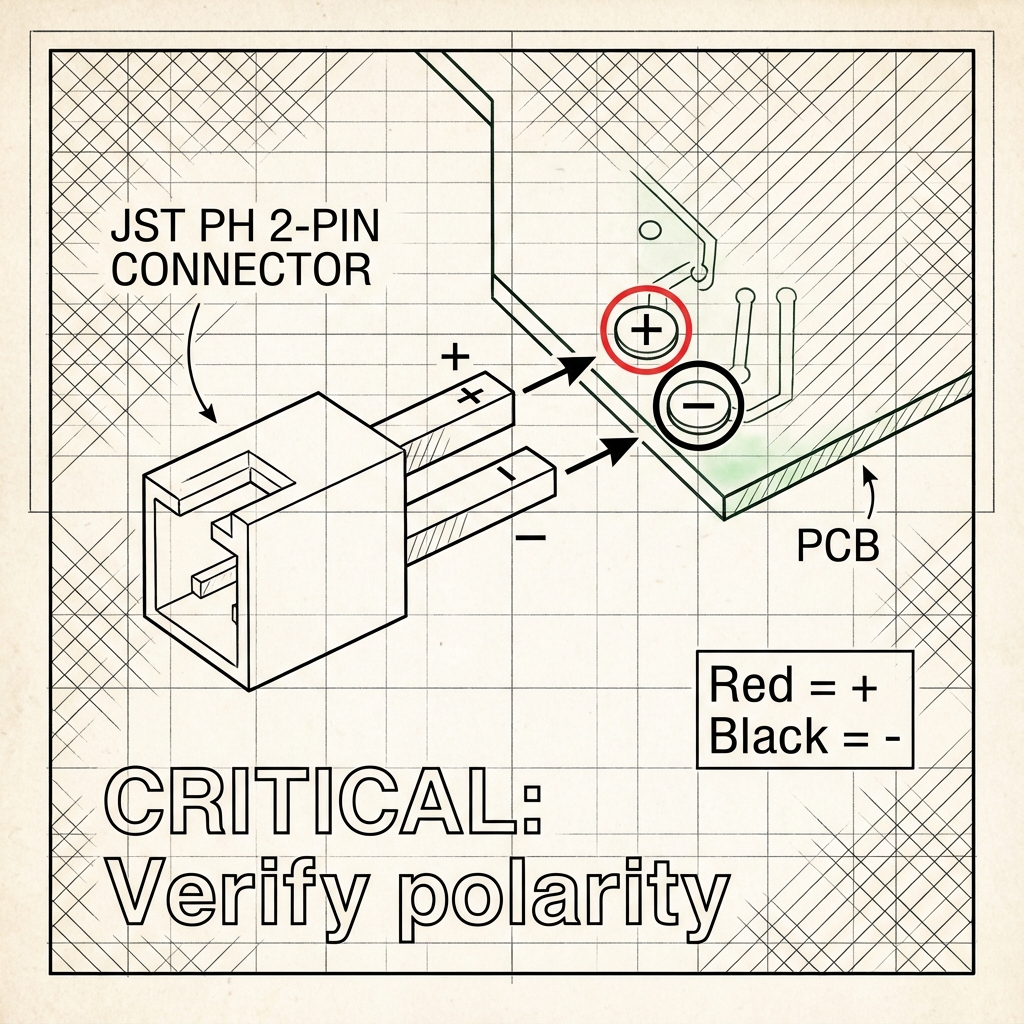
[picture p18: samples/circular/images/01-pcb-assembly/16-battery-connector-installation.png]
Battery Connector Installation


1. **Connector Type**:
   - JST PH 2-pin connector
   - Identify positive and negative terminals
   - Match with PCB markings (+ and -)

2. **Installation**:
   - Insert connector from bottom of PCB
   - Solder both pins
   - **CRITICAL**: Verify polarity - reversed connection will damage battery and circuit

**Verification**: Double-check polarity before connecting battery.

#### 9.3 SWD Programming Header (P1)

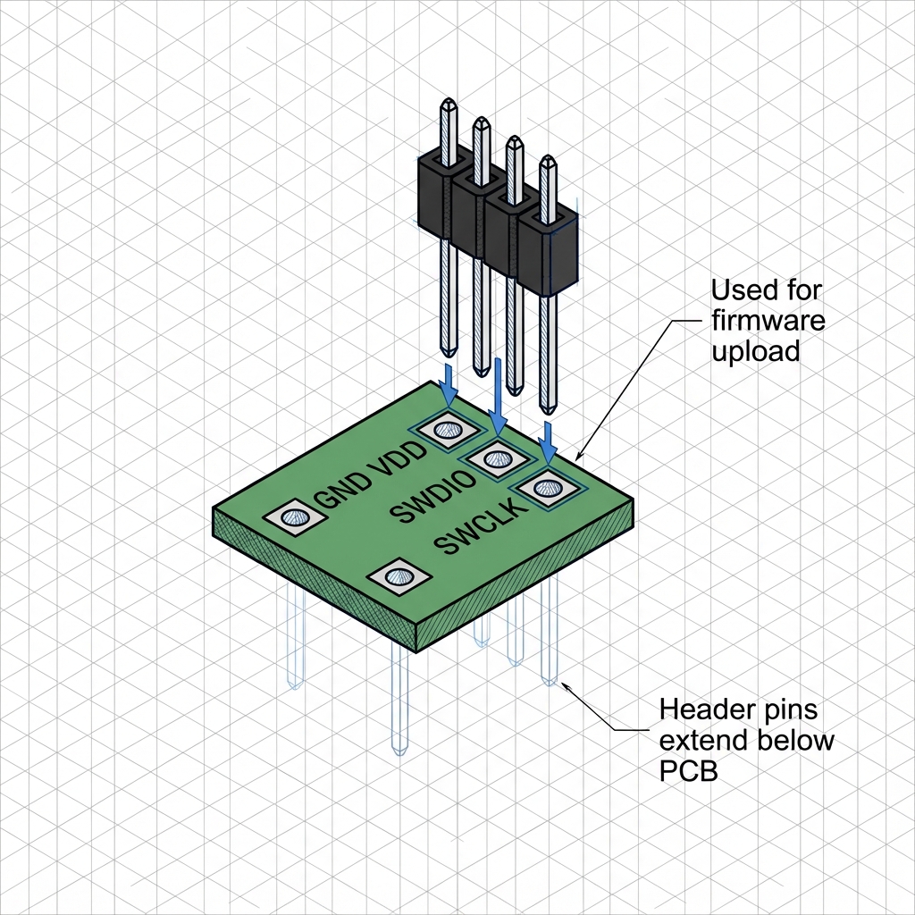
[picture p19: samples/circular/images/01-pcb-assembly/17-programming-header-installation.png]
Programming Header Installation


1. **Header Installation**:
   - 4-pin header for ST-Link programming
   - Insert header from bottom of PCB
   - Solder all 4 pins
   - Header pins should extend below PCB for programming access

2. **Pin Configuration** (for reference):
   - Pin 1: VDD (3.3V)
   - Pin 2: SWDIO
   - Pin 3: SWCLK
   - Pin 4: GND

**Verification**: Check pin alignment and solder quality.

### Step 10: PCB Assembly Verification

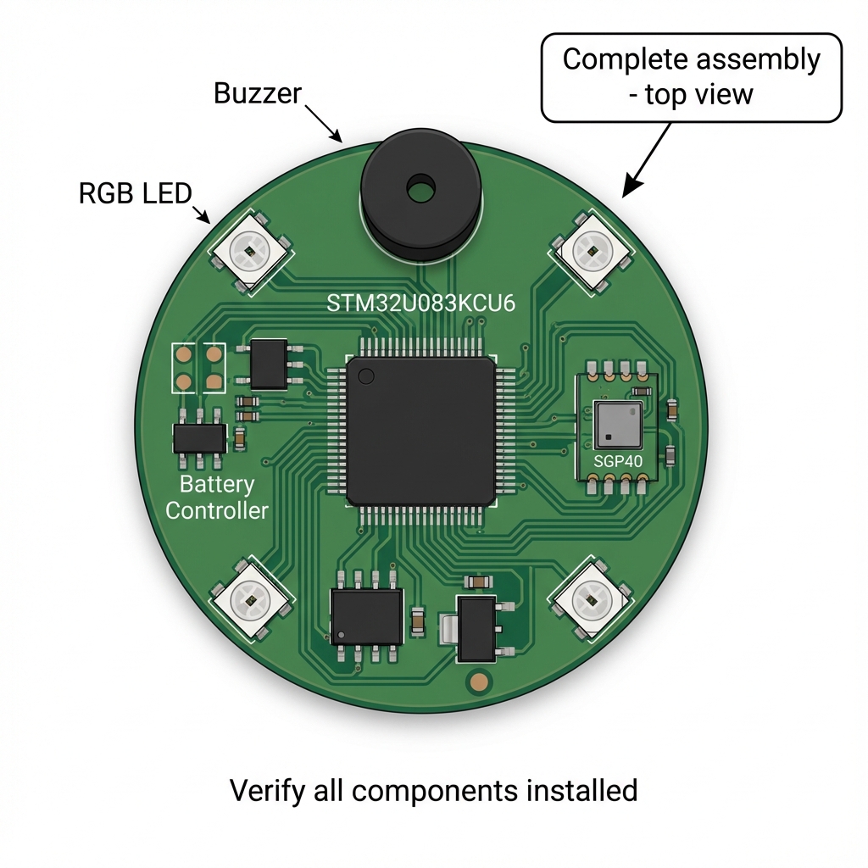
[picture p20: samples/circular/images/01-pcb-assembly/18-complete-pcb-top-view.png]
Complete PCB Top View


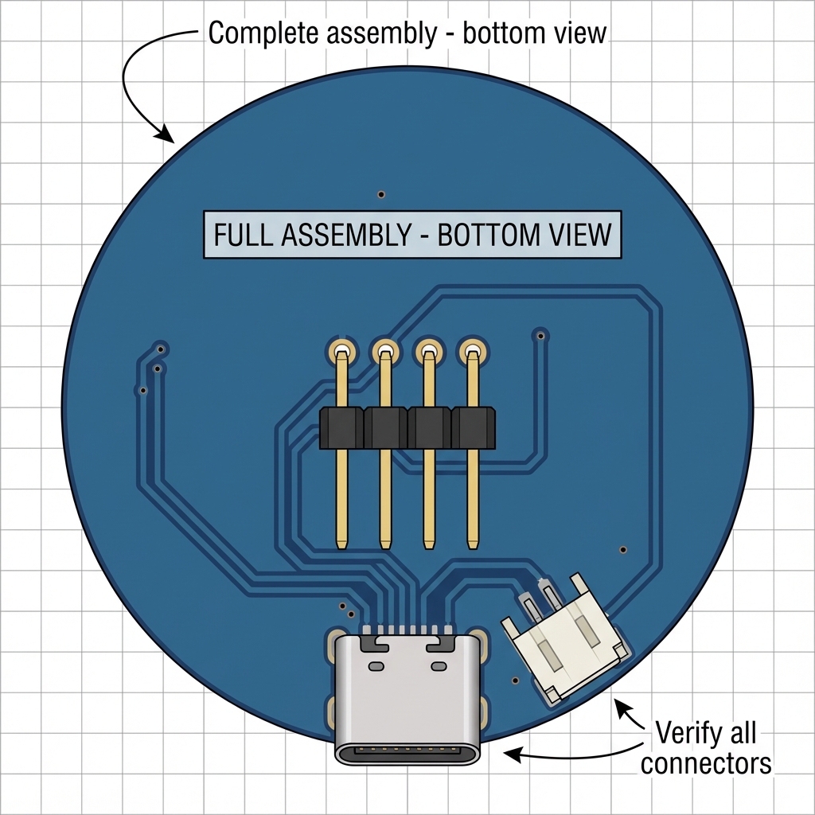
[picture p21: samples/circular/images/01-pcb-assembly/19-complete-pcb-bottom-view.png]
Complete PCB Bottom View


1. **Visual Inspection**:
   - Check all components are installed
   - Verify component orientations
   - Look for solder bridges
   - Check for cold solder joints
   - Verify no components are damaged

2. **Continuity Testing**:
   - Test power rails (VDD to GND should not be shorted)
   - Verify I2C bus connections (SDA, SCL)
   - Check USB-C connector pins
   - Test battery connector polarity

3. **Component Verification**:
   - Verify all resistors and capacitors are installed
   - Check all ICs are properly oriented
   - Confirm LEDs are correctly placed
   - Verify sensor is properly mounted

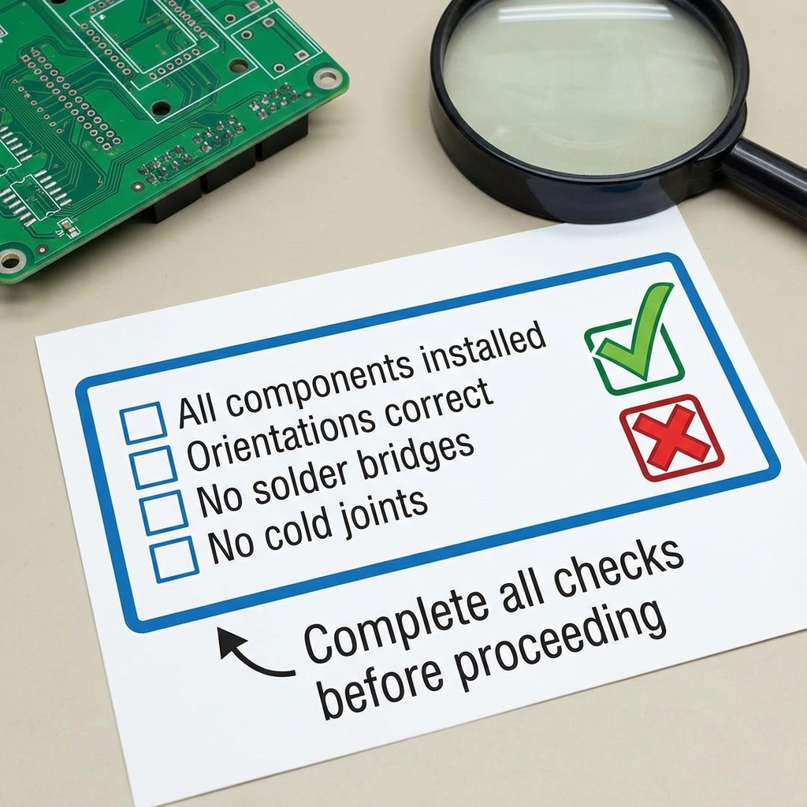
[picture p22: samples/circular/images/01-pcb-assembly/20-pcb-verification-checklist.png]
PCB Verification Checklist


---

## Component Installation

### Step 11: Battery Installation

⚠️ **BATTERY SAFETY**: Handle battery with care. Never short-circuit terminals.

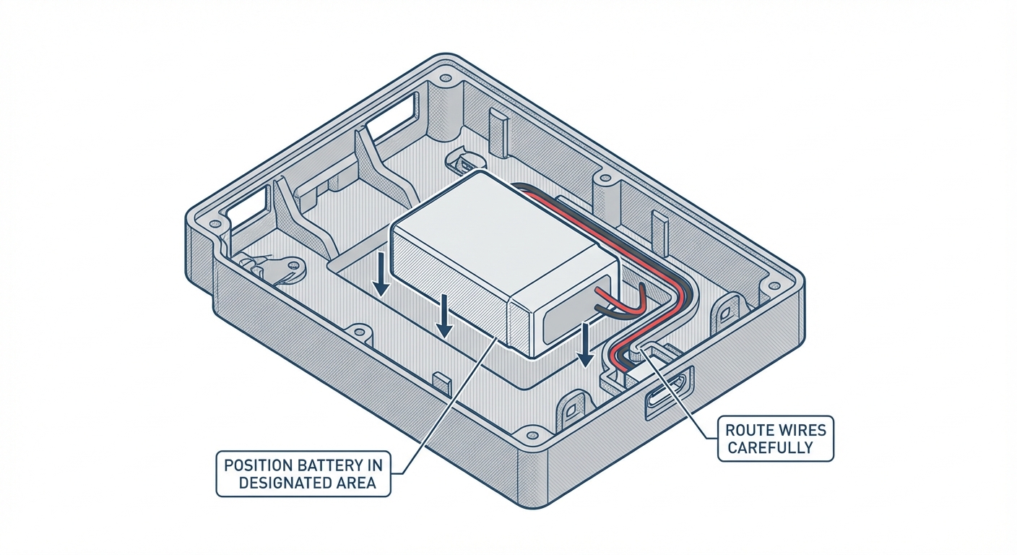
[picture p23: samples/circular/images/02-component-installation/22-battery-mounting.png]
Battery Mounting


1. **Battery Preparation**:
   - Verify battery specifications match BOM (3.7V, 200mAh minimum)
   - Check battery for any physical damage
   - Verify battery protection circuit is present

2. **Battery Mounting**:
   - Apply double-sided adhesive to battery back
   - Position battery in bottom enclosure half
   - Ensure battery does not interfere with PCB placement
   - Route battery wires to connector location

3. **Battery Connection**:
   - **DO NOT CONNECT YET** - wait until final assembly
   - Verify connector polarity matches battery wires
   - Red wire = Positive (+)
   - Black wire = Negative (-)

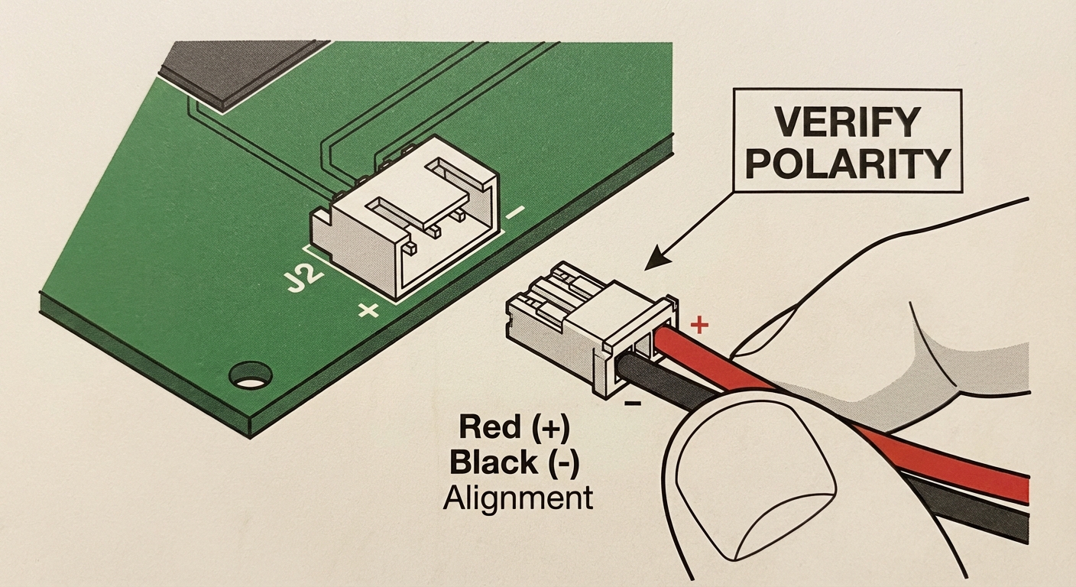
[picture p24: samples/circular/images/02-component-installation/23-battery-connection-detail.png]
Battery Connection Detail


**Verification**: 
- Battery fits securely in enclosure
- Wires are long enough to reach connector
- Polarity is clearly marked

---

## Enclosure Assembly

### Step 12: Prepare Enclosure Parts

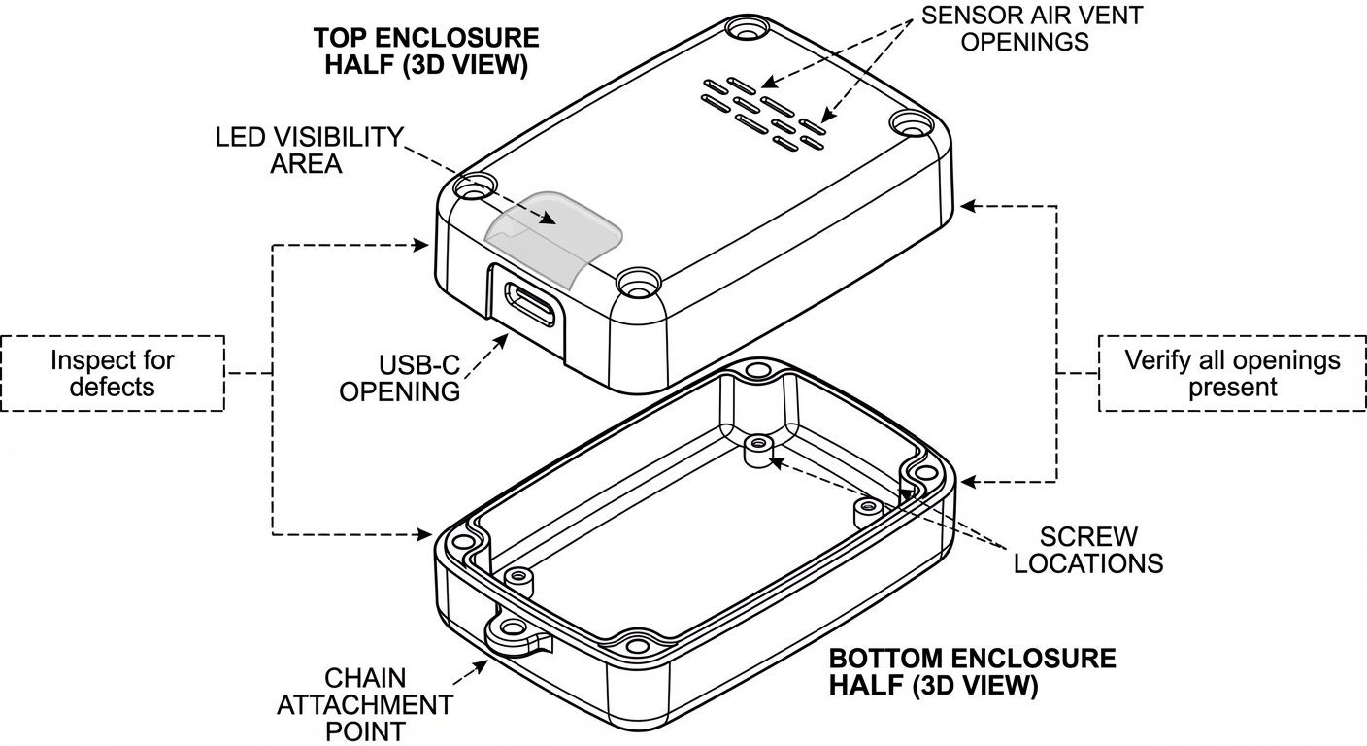
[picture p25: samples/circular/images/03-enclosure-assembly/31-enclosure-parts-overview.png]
Enclosure Parts Overview


1. **Inspect 3D Printed Parts**:
   - Check top and bottom halves for defects
   - Verify all mounting holes are clear
   - Check USB-C opening alignment
   - Ensure sensor air vent openings are present
   - Lightly sand any rough surfaces

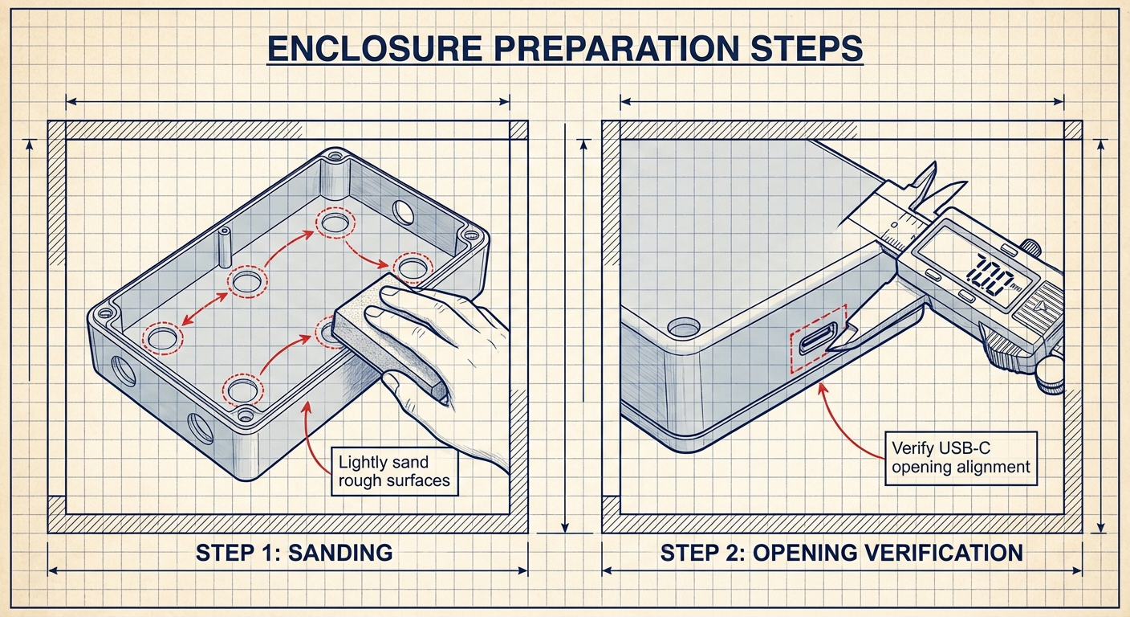
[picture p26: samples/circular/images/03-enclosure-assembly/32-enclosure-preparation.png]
Enclosure Preparation


2. **Test Fit PCB**:
   - Place PCB in bottom enclosure
   - Verify PCB fits without forcing
   - Check USB-C connector aligns with opening
   - Ensure sensor vents align with enclosure openings
   - Verify LEDs are visible through enclosure

### Step 13: Install PCB into Enclosure

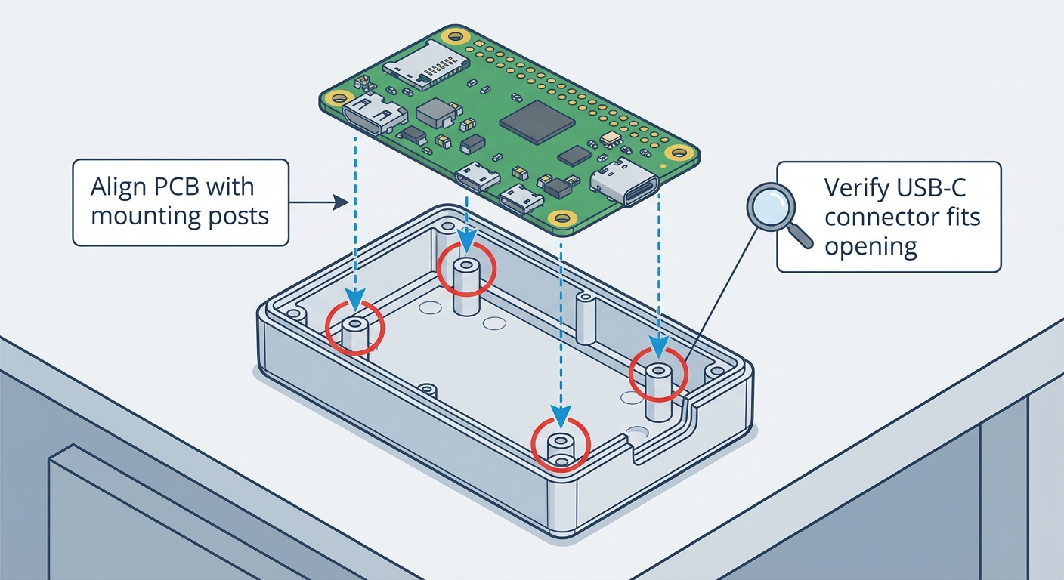
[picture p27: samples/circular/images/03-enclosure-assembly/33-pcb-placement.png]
PCB Placement


1. **Place PCB**:
   - Position PCB in bottom enclosure half
   - Align mounting holes with enclosure posts
   - Verify USB-C connector protrudes through opening
   - Check sensor is properly positioned

2. **Install Spacers**:
   - Place M1.6 spacers on mounting posts
   - Spacers provide clearance between PCB and enclosure

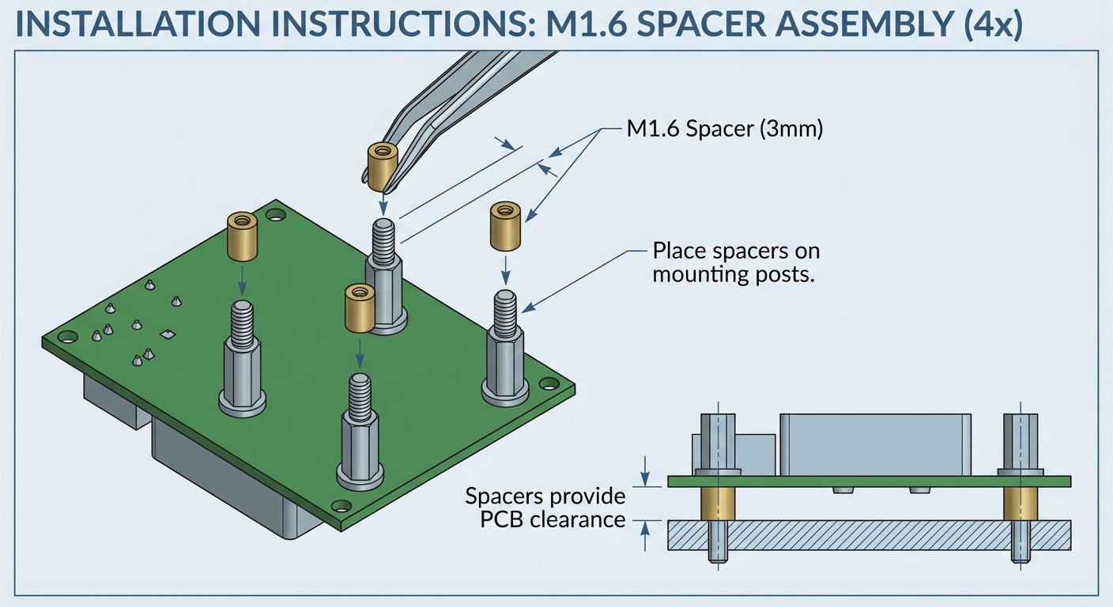
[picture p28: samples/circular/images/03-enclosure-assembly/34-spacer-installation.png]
Spacer Installation


3. **Secure PCB**:
   - Use M1.6x4 screws to secure PCB
   - Tighten screws gently - do not overtighten
   - Verify PCB is secure but not stressed

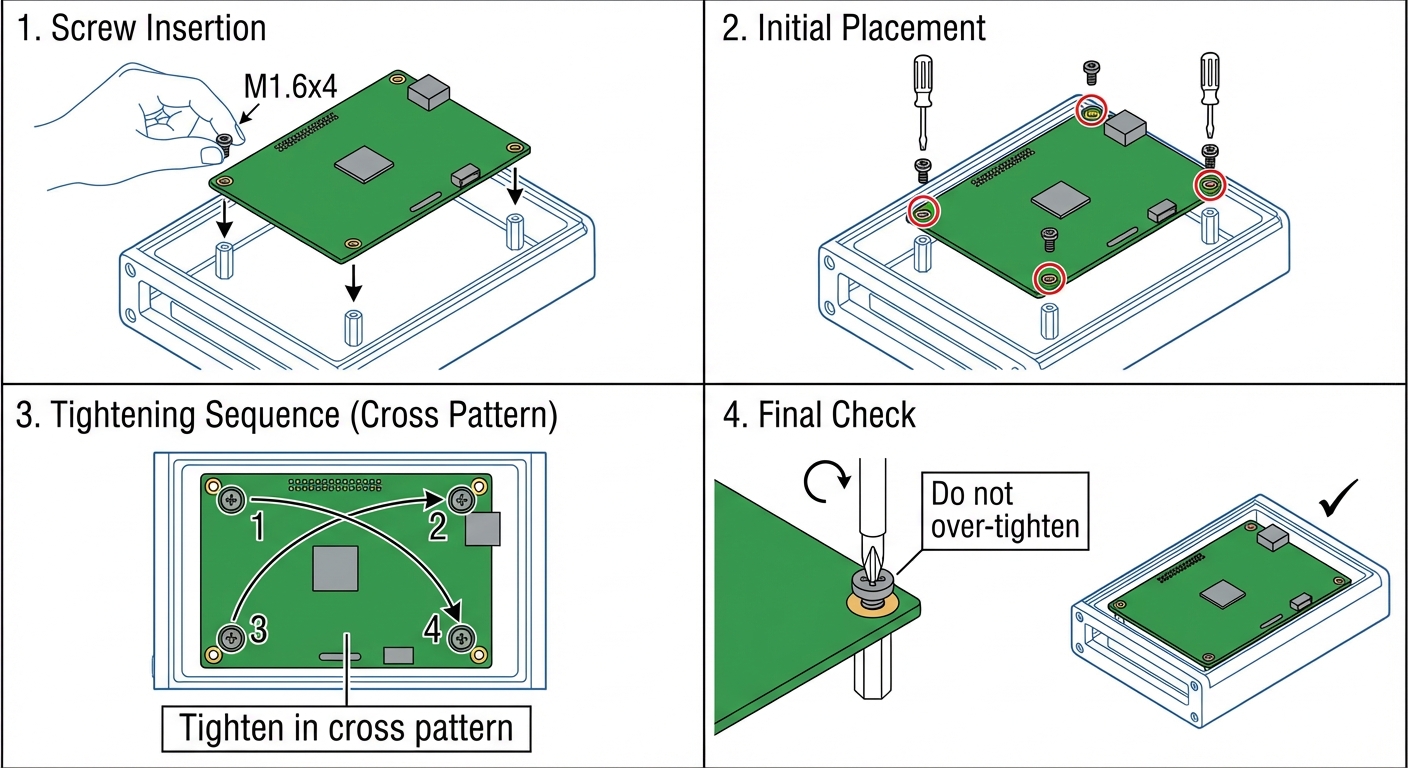
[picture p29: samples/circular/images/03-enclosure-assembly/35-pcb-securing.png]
PCB Securing


**Verification**: 
- PCB is securely mounted
- All connectors align with openings
- No components are touching enclosure walls

### Step 14: Connect Battery

⚠️ **FINAL CHECK BEFORE CONNECTING**:

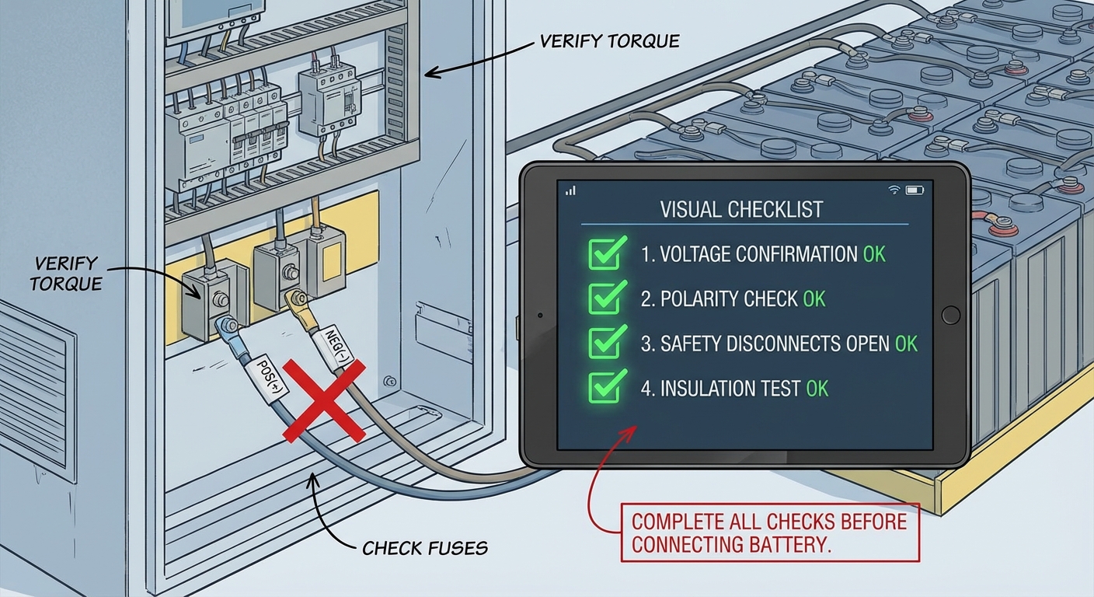
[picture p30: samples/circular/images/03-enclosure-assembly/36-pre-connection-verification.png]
Pre-Connection Verification

- [ ] All components verified
- [ ] No short circuits detected
- [ ] Battery polarity confirmed
- [ ] Connector orientation verified

1. **Connect Battery**:
   - Align battery connector with PCB connector
   - Verify polarity one more time
   - Gently push connectors together
   - Listen for click indicating secure connection

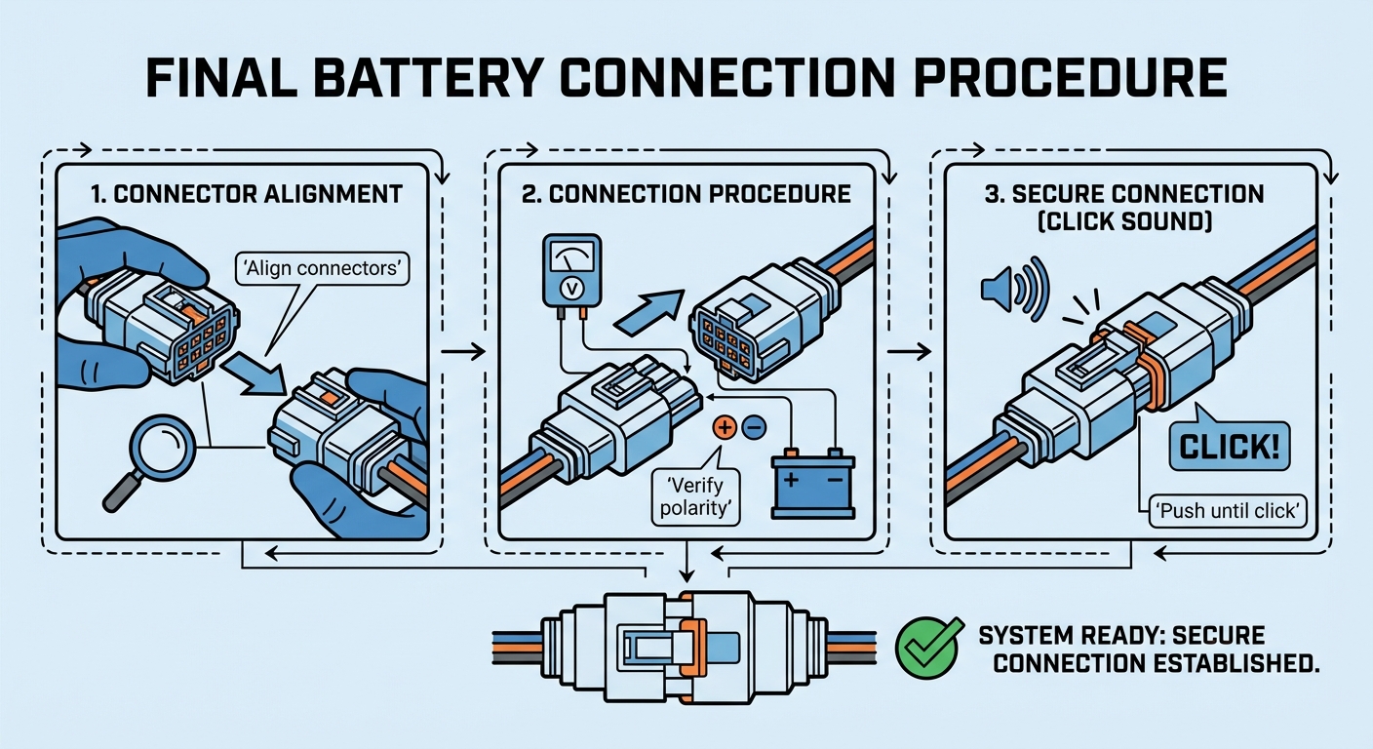
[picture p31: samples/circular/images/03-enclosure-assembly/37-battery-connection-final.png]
Battery Connection Final


2. **Initial Power Test**:
   - Device should power on (if firmware is loaded)
   - LEDs may light up
   - Check for any unusual behavior
   - If smoke or heat detected, disconnect immediately

**Verification**: Device powers on without issues.

### Step 15: Close Enclosure

1. **Final Inspection**:
   - Verify all components are properly positioned
   - Check battery wires are not pinched
   - Ensure sensor vents are clear
   - Verify USB-C connector is accessible

2. **Align Enclosure Halves**:
   - Place top enclosure half over bottom
   - Align mounting holes
   - Verify proper fit

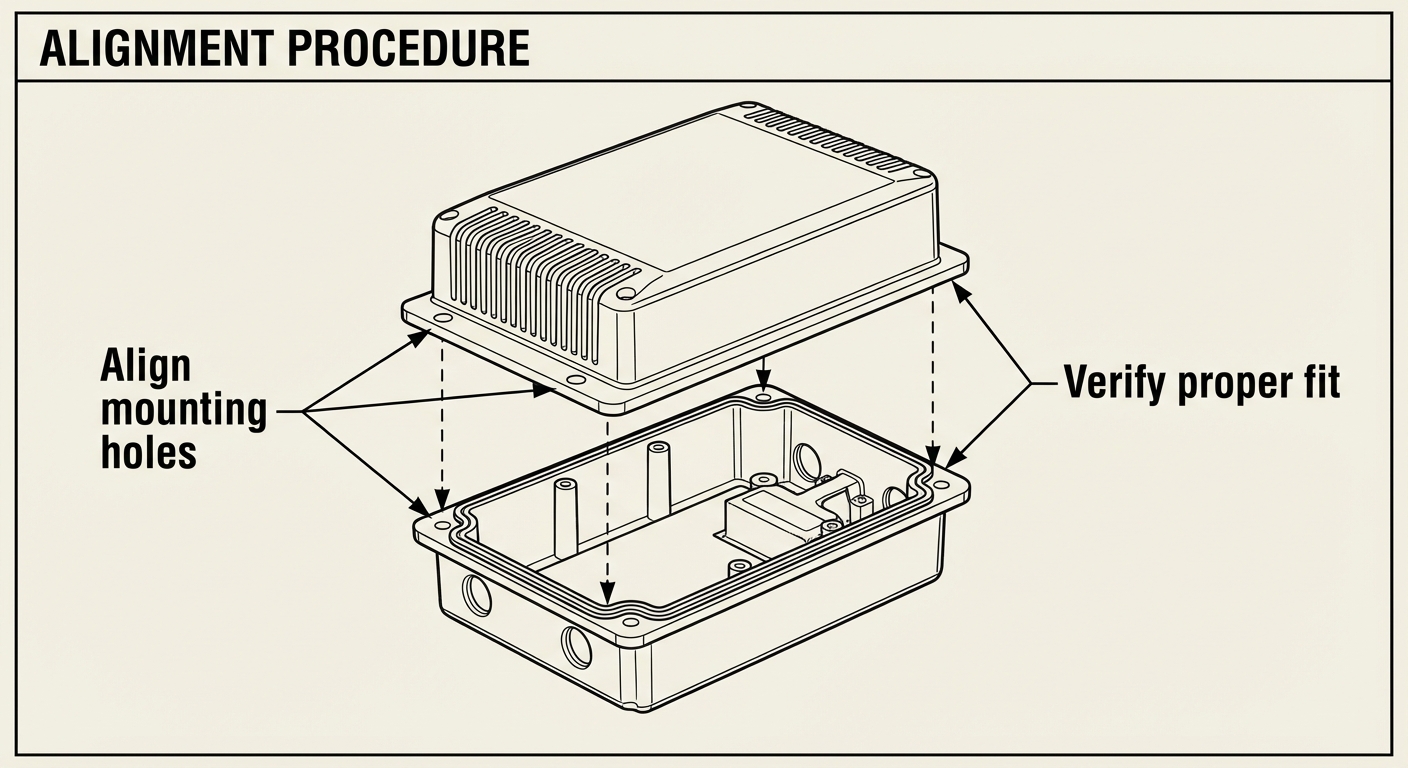
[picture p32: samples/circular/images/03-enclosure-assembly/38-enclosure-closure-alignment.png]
Enclosure Closure Alignment


3. **Secure Enclosure**:
   - Use remaining M1.6x4 screws
   - Tighten evenly in cross pattern
   - Do not overtighten - may crack 3D printed parts

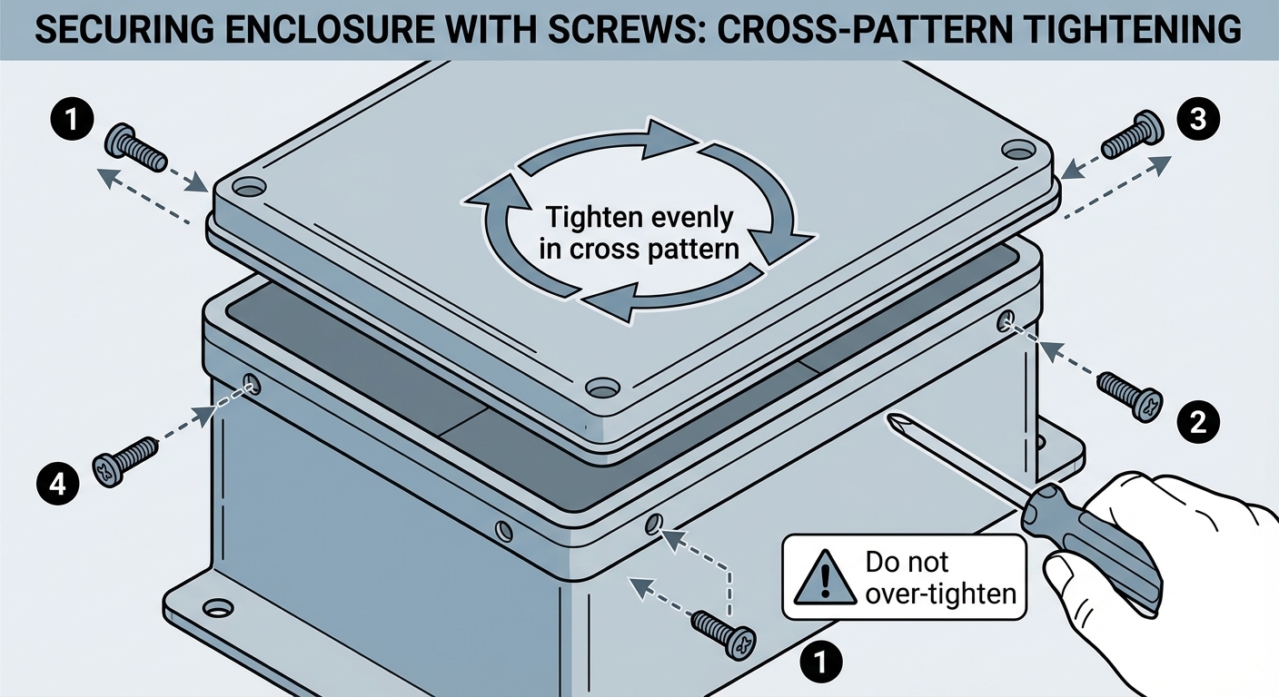
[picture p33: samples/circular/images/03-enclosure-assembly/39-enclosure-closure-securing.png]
Enclosure Closure Securing


4. **Final Check**:
   - Verify enclosure is secure
   - Check all openings are clear
   - Ensure device can be charged via USB-C

### Step 16: Attach Necklace Chain

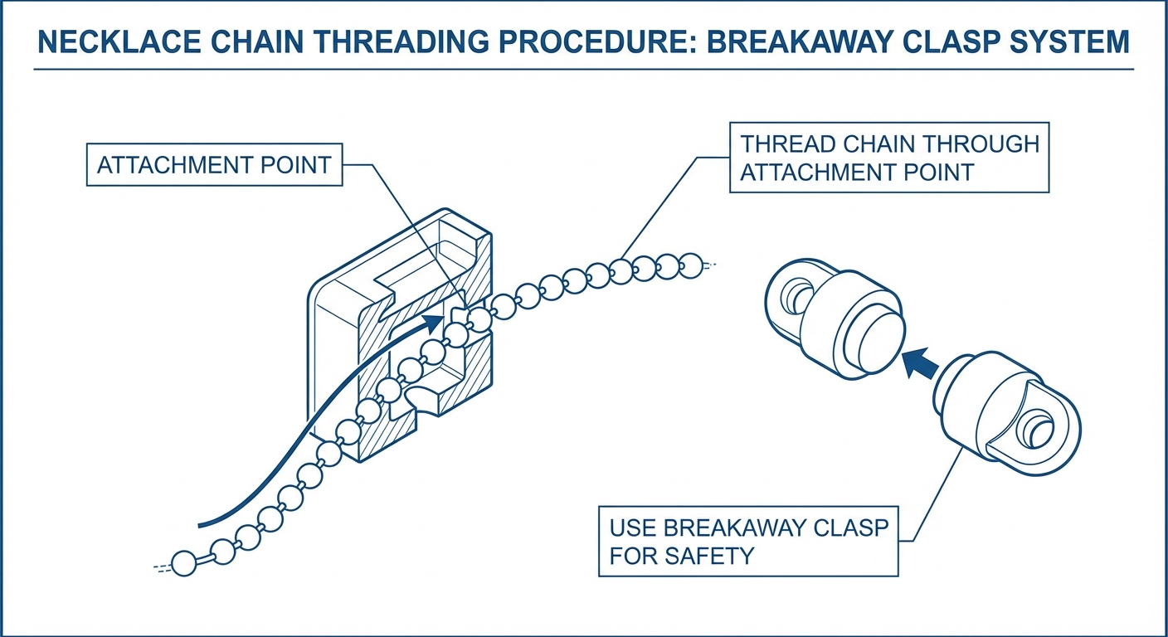
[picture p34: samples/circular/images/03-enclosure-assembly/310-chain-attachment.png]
Chain Attachment


1. **Chain Attachment**:
   - Thread chain through attachment point on pendant
   - Use breakaway clasp for safety
   - Adjust chain length as desired

2. **Final Assembly Check**:
   - Verify pendant hangs properly
   - Check chain does not interfere with USB-C port
   - Ensure device is comfortable to wear

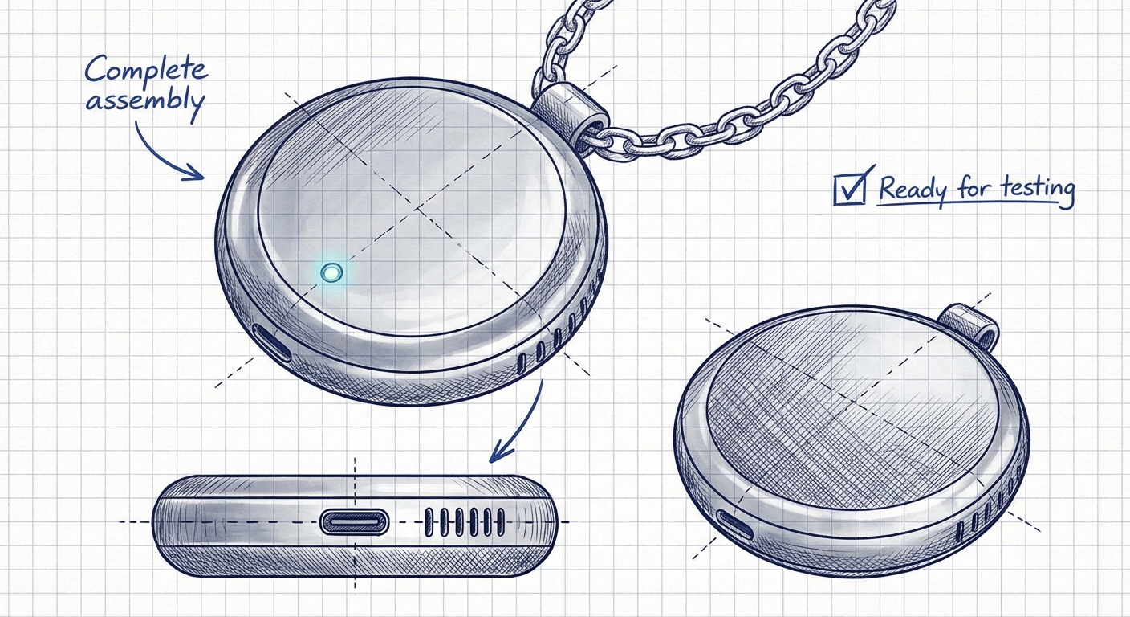
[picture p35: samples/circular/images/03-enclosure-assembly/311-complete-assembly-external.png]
Complete Assembly External View


---

## Testing and Calibration

### Step 17: Power-On Test

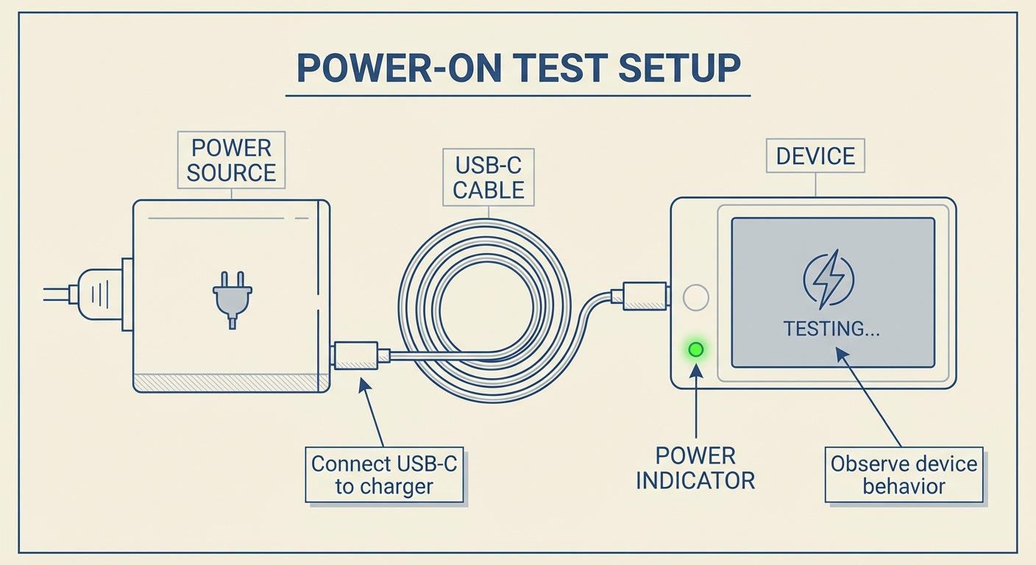
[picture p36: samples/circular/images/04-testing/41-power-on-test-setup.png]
Power-On Test Setup


1. **Initial Power Test**:
   - Connect USB-C cable to charger
   - Plug into power source
   - Observe device behavior:
     - LEDs should indicate charging status
     - No smoke or unusual heat
     - No error beeps

2. **Voltage Verification** (if multimeter available):
   - Measure voltage at battery connector (should be ~3.7V)
   - Check regulator output (should be 2.5V)
   - Verify no short circuits

### Step 18: Firmware Upload

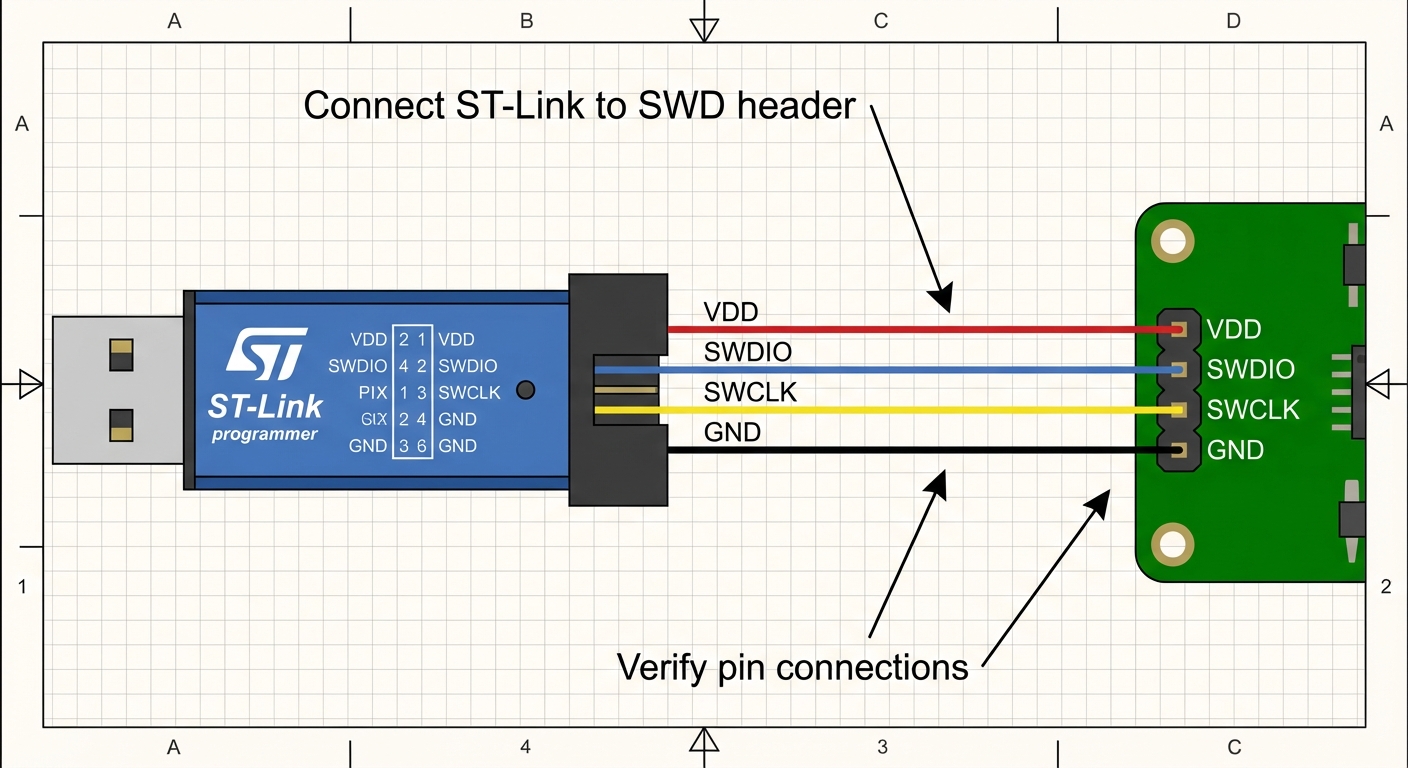
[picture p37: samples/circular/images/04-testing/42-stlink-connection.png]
ST-Link Connection


1. **Connect ST-Link**:
   - Connect ST-Link V2 to SWD header (P1)
   - Verify connections:
     - VDD to VDD
     - SWDIO to SWDIO
     - SWCLK to SWCLK
     - GND to GND

2. **Upload Firmware**:
   - Open Arduino IDE or STM32CubeIDE
   - Select board: STM32U0 series
   - Select programmer: ST-Link
   - Upload firmware
   - Verify successful upload

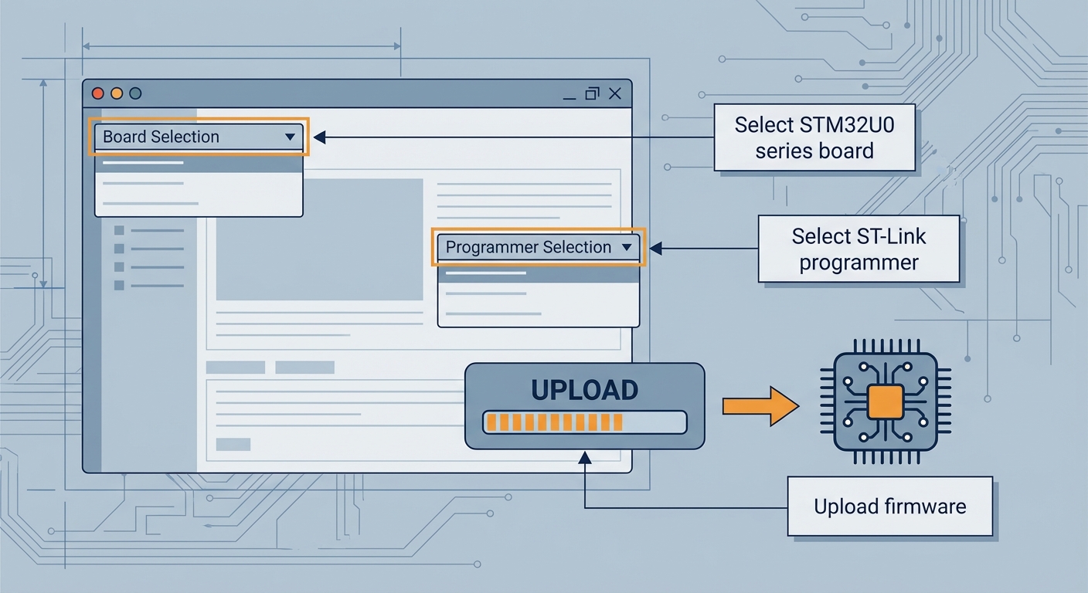
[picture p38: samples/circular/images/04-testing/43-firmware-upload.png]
Firmware Upload


3. **Disconnect ST-Link**:
   - Safely disconnect programming cable
   - Device should now run firmware

### Step 19: Functional Testing

1. **LED Test**:
   - Device should display color based on air quality
   - Green = Good air (TVOC 0-200)
   - Yellow = Moderate air (TVOC 201-300)
   - Red = Poor air (TVOC 301-500)
   - Test by exposing sensor to different air conditions

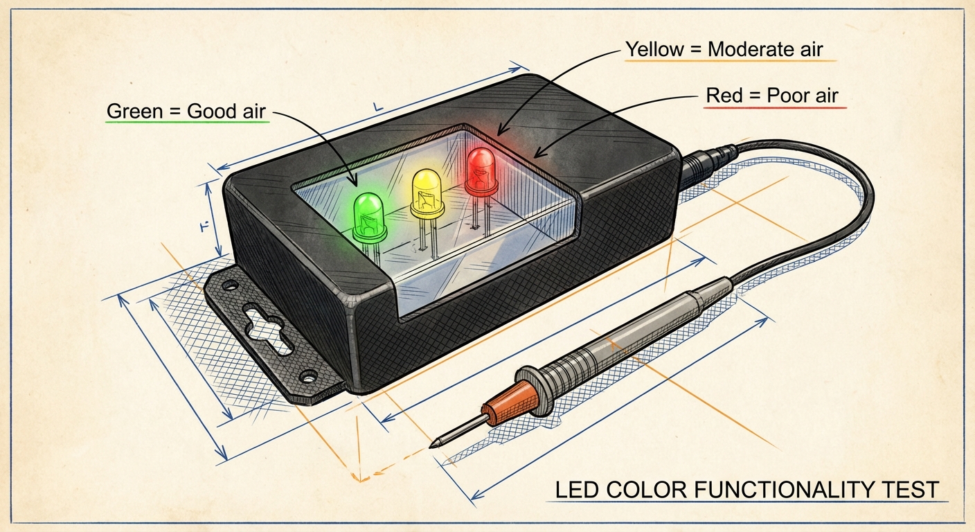
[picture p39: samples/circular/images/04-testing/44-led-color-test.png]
LED Color Test


2. **Sensor Test**:
   - Wave hand near sensor (should detect changes)
   - Test in different environments (indoor, outdoor)
   - Verify sensor responds to air quality changes

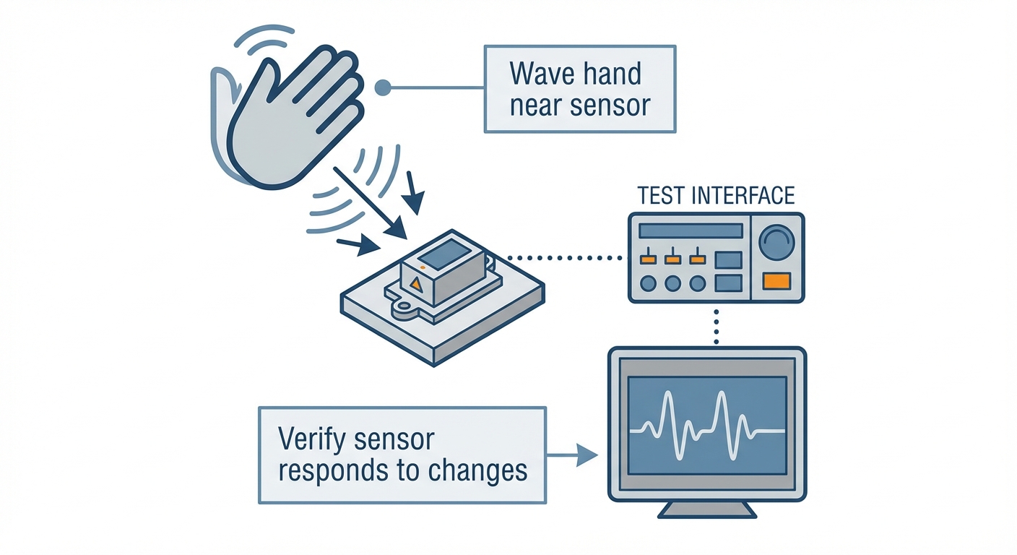
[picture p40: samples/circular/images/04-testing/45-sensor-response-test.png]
Sensor Response Test


3. **Audio Test**:
   - Verify buzzer sounds for alerts
   - Test different alert tones
   - Check volume is appropriate

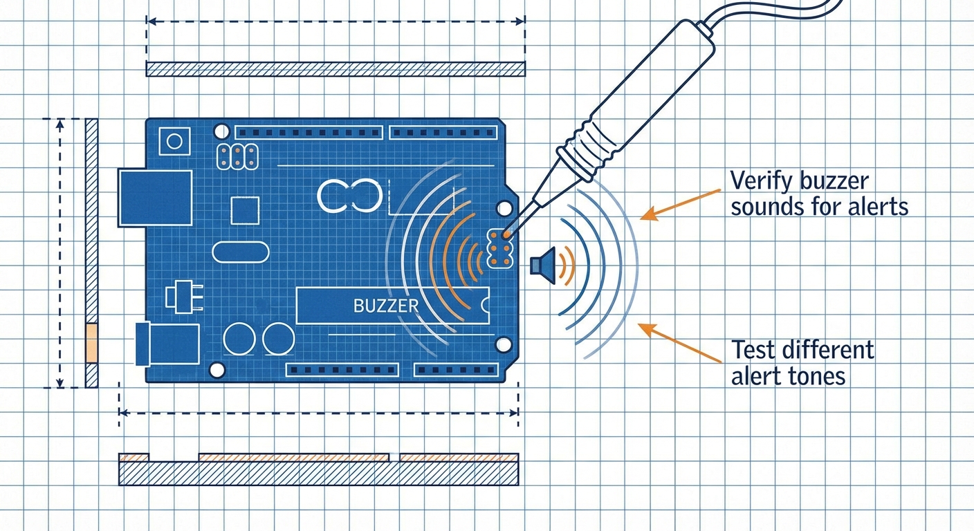
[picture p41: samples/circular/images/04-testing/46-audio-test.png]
Audio Test


4. **Battery Test**:
   - Charge battery fully
   - Monitor battery life over time
   - Verify 16+ hour operation

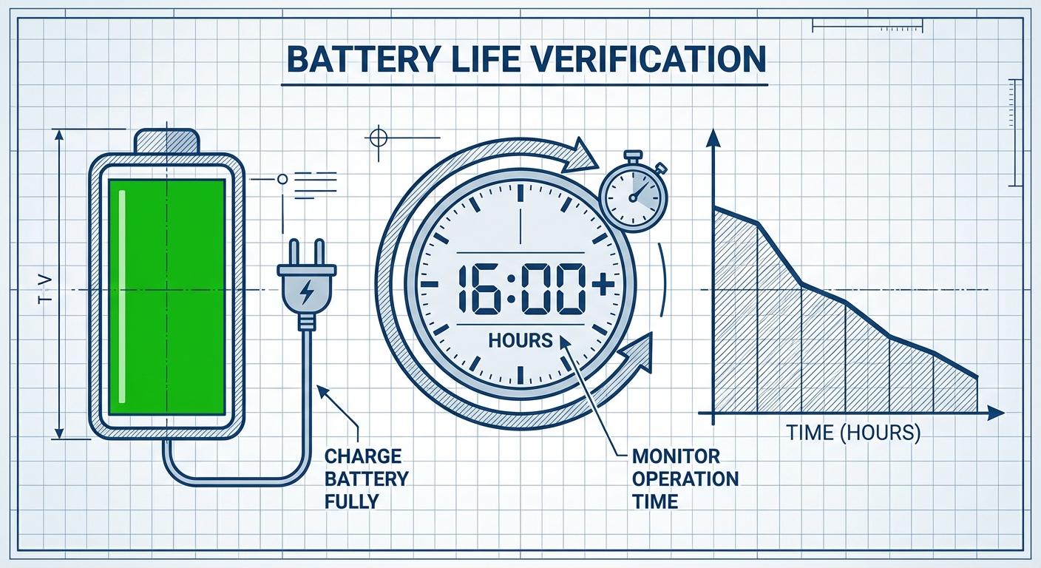
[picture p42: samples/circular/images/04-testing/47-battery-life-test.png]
Battery Life Test


5. **Charging Test**:
   - Connect USB-C charger
   - Verify charging indicator
   - Test charging completes successfully

Charging Test

### Step 20: Calibration (if required)

1. **Sensor Calibration**:
   - Some sensors may require baseline calibration
   - Follow firmware instructions for calibration
   - Calibrate in clean air environment

2. **LED Calibration**:
   - Verify color accuracy
   - Adjust if necessary (via firmware)

---

## Troubleshooting

### Common Issues and Solutions

#### Issue 1: Device Does Not Power On

**Symptoms**: No LEDs, no response when USB connected

Short Circuit Detection

**Possible Causes**:
- Battery not connected or incorrectly connected
- Short circuit on PCB
- Faulty power management IC

**Solutions**:
1. Check battery connection and polarity
2. Verify no short circuits with multimeter
3. Check U3 and U4 are properly installed
4. Verify battery voltage (should be 3.7V)

#### Issue 2: LEDs Do Not Light

**Symptoms**: Device powers on but LEDs remain off

LED Not Working

**Possible Causes**:
- LEDs installed with incorrect polarity
- Faulty LED connections
- Firmware issue

**Solutions**:
1. Verify LED polarity matches PCB markings
2. Check LED solder joints
3. Test LEDs individually with multimeter
4. Verify firmware is correctly uploaded

Orientation Errors

#### Issue 3: Sensor Not Responding

**Symptoms**: LEDs show same color regardless of air quality

Sensor Vent Blockage

**Possible Causes**:
- Sensor not properly connected
- I2C communication issue
- Sensor blocked or damaged

**Solutions**:
1. Verify sensor is properly soldered
2. Check I2C bus connections (SDA, SCL)
3. Ensure sensor vents are not blocked
4. Test sensor with multimeter (check power pins)

#### Issue 4: Battery Not Charging

**Symptoms**: Device works but battery does not charge via USB

USB-C Connection Issues

**Possible Causes**:
- USB-C connector not properly installed
- Charge controller (U3) issue
- Battery protection circuit triggered

**Solutions**:
1. Verify USB-C connector is properly soldered
2. Check U3 installation and orientation
3. Test USB-C connection with multimeter
4. Verify battery protection circuit is functioning

Battery Connection Problems

#### Issue 5: Device Overheats

**Symptoms**: Device becomes hot during operation

**Possible Causes**:
- Short circuit
- Faulty component
- Overcurrent condition

**Solutions**:
1. **IMMEDIATELY DISCONNECT POWER**
2. Check for short circuits
3. Verify all components are correct values
4. Check for damaged components

#### Issue 6: Enclosure Does Not Close Properly

**Symptoms**: Enclosure halves do not fit together

**Possible Causes**:
- Components too tall
- PCB not properly seated
- Enclosure printing defects

**Solutions**:
1. Verify all components are properly seated on PCB
2. Check PCB mounting and spacer height
3. Verify 3D printed parts match specifications
4. Lightly sand enclosure if needed

---

## Final Verification

### Step 21: Complete System Check

Perform final verification:

- [ ] Device powers on successfully
- [ ] LEDs display correct colors for air quality
- [ ] Sensor responds to air quality changes
- [ ] Audio alerts function properly
- [ ] Battery charges via USB-C
- [ ] Battery provides 16+ hours of operation
- [ ] Enclosure is secure and properly closed
- [ ] All openings (USB-C, sensor vents) are clear
- [ ] Necklace chain is properly attached
- [ ] Device is comfortable to wear
- [ ] No unusual heat or behavior
- [ ] Firmware functions as expected

### Step 22: Documentation

1. **Record Serial Number** (if applicable)
2. **Note Any Modifications** made during assembly
3. **Document Calibration Values** (if calibrated)
4. **Keep Assembly Notes** for future reference

---

## Maintenance and Care

### Regular Maintenance

1. **Cleaning**:
   - Clean sensor vents periodically
   - Wipe enclosure with soft cloth
   - Avoid harsh chemicals

2. **Battery Care**:
   - Charge battery regularly
   - Avoid complete discharge
   - Store in cool, dry place

3. **Inspection**:
   - Periodically check for damage
   - Verify all functions still work
   - Check battery health

### Storage

- Store device in protective case
- Keep battery charged (50-80% for long-term storage)
- Avoid extreme temperatures
- Protect from moisture

---

## Support and Resources

### Additional Resources

- **Schematic Diagrams**: Available in project repository
- **Firmware Code**: Available in project repository
- **3D Model Files**: STL files for enclosure printing
- **Community Forums**: [Link to project discussion forum]

### Getting Help

If you encounter issues not covered in this guide:

1. Check troubleshooting section
2. Review schematic and PCB layout
3. Consult project documentation
4. Post questions in project forum
5. Contact project maintainers

---

## Appendix

### A. Component Datasheets

Key component datasheets for reference:
- STM32U083KCU6: [STMicroelectronics website]
- SGP40: [Sensirion website]
- MCP73832: [Microchip website]
- ADP150: [Analog Devices website]

### B. Tool Recommendations

Recommended tools for best results:
- Hakko FX-888D soldering station
- Weller WES51 (alternative)
- Kester 44 rosin core solder
- Chemtronics solder wick

### C. Additional Notes

- Assembly time may vary based on experience level
- First-time builders should allow extra time
- Practice soldering on scrap PCB if new to SMD work
- Take breaks to avoid fatigue and mistakes

---

**Document Control:**
- Prepared by: ProtoAI Design System
- Reviewed by: [To be assigned]
- Approved by: [To be assigned]
- Next Review Date: [To be determined]

**Revision History:**
- v1.0 (2025-12-06): Initial release

---

**End of Assembly Instructions**

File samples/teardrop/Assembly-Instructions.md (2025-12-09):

# Assembly Instructions
## Air Quality Monitoring Necklace Pendant - Teardrop Casing Variant

**Project Name:** Air Quality Monitoring Necklace Pendant (Teardrop Casing - Refined Design)  
**Document Version:** 1.0  
**Date:** 2025-12-06  
**Design Variant:** Refined (Teardrop) - Generated from refined design prompt  
**Estimated Assembly Time:** 2-3 hours  
**Difficulty Level:** Intermediate (requires basic soldering skills)

---

## Table of Contents

1. [Introduction](#introduction)
2. [Safety Precautions](#safety-precautions)
3. [Required Tools and Equipment](#required-tools-and-equipment)
4. [Pre-Assembly Checklist](#pre-assembly-checklist)
5. [PCB Assembly](#pcb-assembly)
6. [Component Installation](#component-installation)
7. [Enclosure Assembly](#enclosure-assembly)
8. [Testing and Calibration](#testing-and-calibration)
9. [Troubleshooting](#troubleshooting)
10. [Final Verification](#final-verification)

---

## Introduction

This document provides step-by-step instructions for assembling the Air Quality Monitoring Necklace Pendant with **teardrop-shaped casing**. The device is a compact, wearable pendant that monitors air quality using a TVOC sensor and provides visual feedback through RGB LEDs.

### Device Overview

The pendant consists of:
- **Main PCB**: 32.5mm diameter circular board with all electronic components (unchanged from original design)
- **Enclosure**: 3D printed teardrop-shaped top and bottom halves (wider at top, tapering to pointed bottom)
- **Battery**: Rechargeable Li-Po battery (200mAh, 3.7V)
- **Necklace Chain**: Adjustable chain or cord with breakaway clasp

**Note**: The PCB remains circular (32.5mm diameter) and fits within the teardrop-shaped enclosure cavity. Only the enclosure shape has changed from the original circular design.

### Key Features

- Real-time TVOC (Total Volatile Organic Compounds) monitoring
- Color-coded LED feedback (Green/Yellow/Red)
- Audio alerts via piezoelectric buzzer
- USB-C charging capability
- All-day battery life (16+ hours)
- Elegant teardrop pendant design

---

## Safety Precautions

⚠️ **IMPORTANT: Read all safety precautions before beginning assembly**

1. **ESD Protection**: Always use an anti-static mat and wrist strap when handling components. Static electricity can damage sensitive ICs.

2. **Soldering Safety**:
   - Work in a well-ventilated area
   - Use safety glasses to protect eyes from solder splashes
   - Keep soldering iron in a secure holder when not in use
   - Allow components to cool before handling

3. **Battery Safety**:
   - Never short-circuit the battery terminals
   - Do not puncture, crush, or expose battery to extreme heat
   - Use only the specified battery type and capacity
   - Charge battery only when properly installed in device

4. **Chemical Safety**:
   - Avoid inhaling flux fumes during soldering
   - Wash hands after handling solder and flux
   - Keep cleaning solvents away from heat sources

5. **General Safety**:
   - Disconnect power before making any modifications
   - Double-check component orientation before soldering
   - Verify polarity of all polarized components

---

## Required Tools and Equipment

### Essential Tools

| Tool | Specification | Purpose |
|---|---|---|
| Soldering Iron | 30-40W, adjustable temperature (300-400°C) | Component soldering |
| Solder | Lead-free, 0.5-0.8mm diameter, rosin core | Electrical connections |
| Solder Wick | 2-3mm width | Desoldering and cleanup |
| Flux | Rosin-based, no-clean | Improved solder flow |
| Tweezers | ESD-safe, fine tip | Component placement |
| Wire Cutters | Flush cut | Lead trimming |
| Multimeter | Digital, basic functions | Continuity and voltage testing |
| Magnifying Glass | 3-5x magnification | Inspection of small components |
| Anti-static Mat | ESD-safe workspace | Static protection |
| Anti-static Wrist Strap | ESD-safe | Personal static protection |

### Optional but Recommended

- Hot air rework station (for SMD components)
- Solder paste stencil (for batch assembly)
- Component organizer trays
- Helping hands tool
- Isopropyl alcohol and lint-free wipes (for cleaning)

### Software Tools

- ST-Link V2 programmer (for firmware upload)
- USB-C cable (for charging and programming)
- Arduino IDE or STM32CubeIDE (for firmware development)

---

## Pre-Assembly Checklist

Before beginning assembly, verify you have all required components:

### Component Verification

- [ ] PCB received and inspected for damage
- [ ] All components from BOM verified and organized
- [ ] 3D printed teardrop enclosure parts received (top and bottom halves)
- [ ] Battery received and checked for damage
- [ ] Necklace chain/cord received
- [ ] All tools available and in working condition

### Workspace Setup

- [ ] Clean, well-lit workspace prepared
- [ ] Anti-static mat laid out
- [ ] Anti-static wrist strap ready
- [ ] Soldering station set up and tested
- [ ] Component organizer trays labeled
- [ ] Safety equipment (glasses, ventilation) ready

### PCB Inspection

1. **Visual Inspection**:
   - Check PCB for scratches, cracks, or delamination
   - Verify all pads are clean and free of oxidation
   - Check for any manufacturing defects
   - Verify silkscreen labels are clear and readable

2. **Continuity Check**:
   - Use multimeter to verify no short circuits between power and ground
   - Check for any obvious manufacturing errors

---

## PCB Assembly

**Note**: The PCB assembly process is identical to the original circular design since the PCB itself remains circular (32.5mm diameter). The PCB fits within the teardrop-shaped enclosure cavity.

### Step 1: Prepare Workspace

PCB Overview

1. Put on anti-static wrist strap and connect to ground
2. Place PCB on anti-static mat
3. Organize components by package size for easy access
4. Set soldering iron to appropriate temperature (350°C for lead-free solder)

**Reference**: See PCB overview image above for component locations.

### Step 2: Install Passive Components (Resistors and Capacitors)

Component Placement Map

**Order of Installation**: Start with smallest components and work up to larger ones. Follow the color-coded installation sequence shown in the component placement map above.

#### 2.1 Install Resistors (R1-R5)

Resistor Installation

1. **R1 (10kΩ)**:
   - Locate R1 position on PCB (check silkscreen)
   - Verify resistor value using multimeter (should read ~10kΩ)
   - Place resistor on PCB pads
   - Verify orientation (resistors are non-polarized)
   - Solder one pad, check alignment, then solder second pad
   - Trim excess leads flush to board

2. **R2 (4.7kΩ)**:
   - Repeat process for R2
   - Verify value: ~4.7kΩ

3. **R3 (2.2kΩ)**:
   - Repeat process for R3
   - Verify value: ~2.2kΩ

4. **R4 (100Ω, 4x)**:
   - Install all four R4 resistors
   - Verify value: ~100Ω each

5. **R5 (220Ω, 4x)**:
   - Install all four R5 resistors
   - Verify value: ~220Ω each

**Verification**: Use multimeter to check each resistor value after installation.

#### 2.2 Install Capacitors (C1-C7)

Capacitor Installation

1. **C1, C2 (10µF)**:
   - Locate C1 and C2 positions
   - **IMPORTANT**: Ceramic capacitors are non-polarized
   - Place capacitors on pads
   - Solder both pads
   - Trim excess leads

2. **C3 (4.7µF)**:
   - Install C3 using same process

3. **C4-C7 (100nF, 4x)**:
   - Install all four 100nF capacitors
   - These are decoupling capacitors - ensure they're close to their respective ICs

**Verification**: Check for proper solder joints and no bridges between pads.

### Step 3: Install Power Management Components

#### 3.1 Install Voltage Regulator (U4 - ADP150)

Voltage Regulator Installation

1. **Identify Pin 1**:
   - Locate pin 1 indicator on IC (usually a dot or notch)
   - Match with pin 1 indicator on PCB silkscreen

2. **Placement**:
   - Apply small amount of flux to pads
   - Place IC on pads, ensuring pin 1 alignment
   - Verify all pins are on their respective pads

3. **Soldering**:
   - For TSOT-23 package, use fine-tip soldering iron
   - Solder pin 1 first to secure position
   - Solder remaining pins carefully
   - Check for solder bridges between pins
   - Use solder wick to remove any bridges

**Verification**: 
- Check continuity between pins and pads
- Verify no short circuits between adjacent pins

#### 3.2 Install Battery Charge Controller (U3 - MCP73832)

Charge Controller Installation

1. Follow same process as U4
2. **Critical**: Ensure correct orientation (pin 1 to pin 1)
3. This IC manages battery charging - incorrect installation will prevent charging

**Verification**: Check pin alignment and solder quality.

#### 3.3 Install Schottky Diode (D1)

**Note**: Diode orientation is critical. Match the cathode stripe (marked on diode) with the silkscreen marking on PCB.

1. **Identify Cathode**:
   - Diode has a stripe on cathode end
   - Match cathode stripe with silkscreen marking on PCB

2. **Placement and Soldering**:
   - Place diode with correct orientation
   - Solder both pads
   - **WARNING**: Reversed polarity will damage circuit

**Verification**: Check orientation matches silkscreen.

### Step 4: Install Microcontroller (U1 - STM32U083KCU6)

⚠️ **CRITICAL STEP**: This is the most important component. Take extra care.

Microcontroller Overview

1. **Preparation**:
   - Verify microcontroller part number matches BOM
   - Check for any bent pins
   - Clean pads on PCB with isopropyl alcohol

2. **Pin 1 Identification**:
   - Locate pin 1 indicator on IC (usually a dot in corner)
   - Match with pin 1 indicator on PCB (usually a square pad or dot)

Pin 1 Alignment

3. **Placement**:
   - For QFN-48 package, alignment is critical
   - Apply flux to PCB pads
   - Carefully place IC, ensuring pin 1 alignment
   - Verify all pads are visible around IC perimeter

4. **Soldering**:
   - **Method 1 (Hot Air)**:
     - Use hot air rework station
     - Apply heat evenly around IC (350°C, low airflow)
     - Watch for solder to flow and IC to "settle"
     - Allow to cool before moving
   
   - **Method 2 (Soldering Iron)**:
     - Solder corner pins first to secure position
     - Apply flux to all pads
     - Drag solder technique: apply solder to iron tip, drag across pins
     - Use solder wick to remove excess and bridges
     - Check each pin for proper connection

Soldering Methods

5. **Verification**:
   - Inspect all pins under magnification
   - Check for solder bridges
   - Verify no cold solder joints
   - Test continuity between adjacent pins (should be open circuit)

Microcontroller Verification

### Step 5: Install Air Quality Sensor (U2 - SGP40)

Sensor Installation

1. **Sensor Orientation**:
   - SGP40 has air sampling vents on top
   - Ensure vents face upward (away from PCB) when installed
   - Match pin 1 with PCB pin 1 indicator

2. **Placement**:
   - Apply thermal pad to sensor bottom (if specified)
   - Place sensor on PCB pads
   - Verify air vents are not blocked

3. **Soldering**:
   - Use fine-tip soldering iron
   - Solder all 8 pins carefully
   - **IMPORTANT**: Do not overheat sensor - it contains sensitive sensing elements

4. **Air Vent Clearance**:
   - Verify sensor vents have clearance above PCB
   - Ensure teardrop enclosure will not block air flow to sensor

**Verification**: 
- Check sensor is properly seated
- Verify air vents are accessible
- Test I2C communication (requires firmware)

### Step 6: Install RGB LEDs (LED1-LED4)

LED Installation Overview

1. **LED Identification**:
   - EAST1616RGBA1 LEDs have 4 pins (R, G, B, Common Anode)
   - Identify pin 1 (usually marked with dot or different pad shape)
   - Match with PCB silkscreen

2. **Installation Process** (repeat for all 4 LEDs):
   - Place LED on PCB pads
   - Verify pin 1 alignment
   - Solder all 4 pins
   - **IMPORTANT**: LEDs are directional - incorrect orientation will prevent operation

LED Installation Detail

3. **LED Placement**:
   - LEDs should be positioned to maximize visibility through teardrop enclosure openings
   - Ensure LEDs are flush with PCB surface
   - Check that LED lenses are not scratched

**Verification**: 
- Visual inspection of all LED installations
- Verify pin alignment matches silkscreen
- Test LEDs after power-up (requires firmware)

### Step 7: Install Piezoelectric Buzzer (BZ1)

Buzzer Installation

1. **Buzzer Orientation**:
   - Piezoelectric buzzers are polarized
   - Identify positive (+) and negative (-) terminals
   - Match with PCB markings

2. **Placement**:
   - Place buzzer on PCB pads
   - Ensure correct polarity
   - Buzzer should be positioned to allow sound to escape teardrop enclosure

3. **Soldering**:
   - Solder both terminals
   - Verify secure mechanical connection

**Verification**: Check polarity and secure mounting.

### Step 8: Install Crystal Oscillator (Y1)

**Note**: Crystals are non-polarized. Place on PCB pads and solder both terminals.

1. **Crystal Installation**:
   - Crystals are non-polarized
   - Place crystal on PCB pads
   - Solder both terminals
   - Keep leads as short as possible

2. **Mounting Considerations**:
   - Crystal should be close to microcontroller
   - Avoid mechanical stress on crystal

**Verification**: Check solder joints and positioning.

### Step 9: Install Connectors

#### 9.1 USB Type-C Connector (J1)

USB-C Connector Installation

1. **Connector Orientation**:
   - USB-C connectors have specific mounting orientation
   - Match connector keying with PCB cutout
   - Verify connector will align with teardrop enclosure side opening

2. **Placement and Soldering**:
   - Insert connector into PCB from top side
   - Solder all pins (USB-C has many pins - be thorough)
   - Verify connector is flush with PCB surface
   - Check for proper mechanical retention

**Verification**: 
- Verify connector alignment with teardrop enclosure side opening
- Test connector retention (should not wobble)

#### 9.2 Battery Connector (J2)

Battery Connector Installation

1. **Connector Type**:
   - JST PH 2-pin connector
   - Identify positive and negative terminals
   - Match with PCB markings (+ and -)

2. **Installation**:
   - Insert connector from bottom of PCB
   - Solder both pins
   - **CRITICAL**: Verify polarity - reversed connection will damage battery and circuit

**Verification**: Double-check polarity before connecting battery.

#### 9.3 SWD Programming Header (P1)

Programming Header Installation

1. **Header Installation**:
   - 4-pin header for ST-Link programming
   - Insert header from bottom of PCB
   - Solder all 4 pins
   - Header pins should extend below PCB for programming access

2. **Pin Configuration** (for reference):
   - Pin 1: VDD (3.3V)
   - Pin 2: SWDIO
   - Pin 3: SWCLK
   - Pin 4: GND

**Verification**: Check pin alignment and solder quality.

### Step 10: PCB Assembly Verification

Complete PCB Top View

Complete PCB Bottom View

1. **Visual Inspection**:
   - Check all components are installed
   - Verify component orientations
   - Look for solder bridges
   - Check for cold solder joints
   - Verify no components are damaged

2. **Continuity Testing**:
   - Test power rails (VDD to GND should not be shorted)
   - Verify I2C bus connections (SDA, SCL)
   - Check USB-C connector pins
   - Test battery connector polarity

3. **Component Verification**:
   - Verify all resistors and capacitors are installed
   - Check all ICs are properly oriented
   - Confirm LEDs are correctly placed
   - Verify sensor is properly mounted

PCB Verification Checklist

---

## Component Installation

### Step 11: Battery Installation

⚠️ **BATTERY SAFETY**: Handle battery with care. Never short-circuit terminals.

Battery Mounting

1. **Battery Preparation**:
   - Verify battery specifications match BOM (3.7V, 200mAh minimum)
   - Check battery for any physical damage
   - Verify battery protection circuit is present

2. **Battery Mounting**:
   - Apply double-sided adhesive to battery back
   - Position battery in bottom teardrop enclosure half
   - Ensure battery does not interfere with PCB placement
   - Route battery wires to connector location

3. **Battery Connection**:
   - **DO NOT CONNECT YET** - wait until final assembly
   - Verify connector polarity matches battery wires
   - Red wire = Positive (+)
   - Black wire = Negative (-)

Battery Connection Detail

**Verification**: 
- Battery fits securely in teardrop enclosure
- Wires are long enough to reach connector
- Polarity is clearly marked

---

## Enclosure Assembly

### Step 12: Prepare Teardrop Enclosure Parts

Enclosure Parts Overview - Teardrop

1. **Inspect 3D Printed Teardrop Parts**:
   - Check top and bottom teardrop halves for defects
   - Verify teardrop shape: wider at top (35-40mm), tapering to pointed bottom (15-20mm)
   - Verify all mounting holes are clear
   - Check USB-C opening alignment on side wall (near top, wider section)
   - Ensure sensor air vent openings are present
   - Verify side slots (2x, horizontal oval, near top) are present
   - Check attachment loop at top center
   - Lightly sand any rough surfaces, especially curved areas

Enclosure Preparation - Teardrop

2. **Test Fit Circular PCB in Teardrop Enclosure**:
   - Place circular PCB (32.5mm diameter) in bottom teardrop enclosure
   - Verify PCB fits within teardrop cavity without forcing
   - Check minimum 1-2mm clearance on all sides
   - Verify USB-C connector aligns with side opening
   - Ensure sensor vents align with enclosure openings
   - Verify LEDs are visible through enclosure openings
   - Check that PCB does not interfere with teardrop shape

### Step 13: Install PCB into Teardrop Enclosure

PCB Placement - Teardrop

1. **Place PCB**:
   - Position circular PCB in bottom teardrop enclosure half
   - Align mounting holes with enclosure posts
   - Verify PCB fits within teardrop cavity (circular PCB in teardrop shape)
   - Verify USB-C connector protrudes through side opening
   - Check sensor is properly positioned
   - Ensure 1-2mm clearance on all sides

2. **Install Spacers**:
   - Place M1.6 spacers on mounting posts
   - Spacers provide clearance between PCB and teardrop enclosure

Spacer Installation - Teardrop

3. **Secure PCB**:
   - Use M1.6x4 screws to secure PCB
   - Tighten screws gently - do not overtighten (may crack 3D printed parts)
   - Verify PCB is secure but not stressed

PCB Securing - Teardrop

**Verification**: 
- PCB is securely mounted within teardrop enclosure
- All connectors align with openings
- No components are touching teardrop enclosure walls
- Circular PCB fits properly in teardrop cavity

### Step 14: Connect Battery

⚠️ **FINAL CHECK BEFORE CONNECTING**:

Pre-Connection Verification - Teardrop
- [ ] All components verified
- [ ] No short circuits detected
- [ ] Battery polarity confirmed
- [ ] Connector orientation verified

1. **Connect Battery**:
   - Align battery connector with PCB connector
   - Verify polarity one more time
   - Gently push connectors together
   - Listen for click indicating secure connection

Battery Connection Final - Teardrop

2. **Initial Power Test**:
   - Device should power on (if firmware is loaded)
   - LEDs may light up
   - Check for any unusual behavior
   - If smoke or heat detected, disconnect immediately

**Verification**: Device powers on without issues.

### Step 15: Close Teardrop Enclosure

1. **Final Inspection**:
   - Verify all components are properly positioned
   - Check battery wires are not pinched
   - Ensure sensor vents are clear
   - Verify USB-C connector is accessible through side opening
   - Check that circular PCB fits properly within teardrop cavity

2. **Align Teardrop Enclosure Halves**:
   - Place top teardrop enclosure half over bottom
   - Align mounting holes
   - Verify teardrop shapes match perfectly
   - Check attachment loops align at top
   - Verify side slots align
   - Ensure sensor vents align

Enclosure Closure Alignment - Teardrop

3. **Secure Enclosure**:
   - Use remaining M1.6x4 screws
   - Tighten evenly in cross pattern
   - Do not over-tighten - may crack 3D printed teardrop parts

Enclosure Closure Securing - Teardrop

4. **Final Check**:
   - Verify teardrop enclosure is secure
   - Check all openings are clear (USB-C, sensor vents, side slots)
   - Ensure device can be charged via USB-C
   - Verify teardrop shape is maintained

### Step 16: Attach Necklace Chain

Chain Attachment - Teardrop

1. **Chain Attachment**:
   - Thread chain through attachment loop at top of teardrop pendant (wider end)
   - Use breakaway clasp for safety
   - Adjust chain length as desired

2. **Final Assembly Check**:
   - Verify pendant hangs properly with teardrop shape
   - Check chain does not interfere with USB-C port on side
   - Ensure device is comfortable to wear
   - Verify teardrop shape is aesthetically pleasing

Complete Assembly External - Teardrop

---

## Testing and Calibration

### Step 17: Power-On Test

Power-On Test Setup - Teardrop

1. **Initial Power Test**:
   - Connect USB-C cable to charger
   - Plug into power source
   - Observe device behavior:
     - LEDs should indicate charging status
     - No smoke or unusual heat
     - No error beeps

2. **Voltage Verification** (if multimeter available):
   - Measure voltage at battery connector (should be ~3.7V)
   - Check regulator output (should be 2.5V)
   - Verify no short circuits

### Step 18: Firmware Upload

ST-Link Connection - Teardrop

1. **Connect ST-Link**:
   - Connect ST-Link V2 to SWD header (P1)
   - Verify connections:
     - VDD to VDD
     - SWDIO to SWDIO
     - SWCLK to SWCLK
     - GND to GND

2. **Upload Firmware**:
   - Open Arduino IDE or STM32CubeIDE
   - Select board: STM32U0 series
   - Select programmer: ST-Link
   - Upload firmware
   - Verify successful upload

Firmware Upload - Teardrop

3. **Disconnect ST-Link**:
   - Safely disconnect programming cable
   - Device should now run firmware

### Step 19: Functional Testing

1. **LED Test**:
   - Device should display color based on air quality
   - Green = Good air (TVOC 0-200)
   - Yellow = Moderate air (TVOC 201-300)
   - Red = Poor air (TVOC 301-500)
   - Test by exposing sensor to different air conditions
   - Verify LEDs are visible through teardrop enclosure openings

LED Color Test - Teardrop

2. **Sensor Test**:
   - Wave hand near sensor (should detect changes)
   - Test in different environments (indoor, outdoor)
   - Verify sensor responds to air quality changes
   - Ensure sensor vents in teardrop enclosure allow proper air flow

Sensor Response Test - Teardrop

3. **Audio Test**:
   - Verify buzzer sounds for alerts
   - Test different alert tones
   - Check volume is appropriate
   - Ensure sound escapes through teardrop enclosure

Audio Test - Teardrop

4. **Battery Test**:
   - Charge battery fully
   - Monitor battery life over time
   - Verify 16+ hour operation

Battery Life Test - Teardrop

5. **Charging Test**:
   - Connect USB-C charger through side opening
   - Verify charging indicator
   - Test charging completes successfully

Charging Test - Teardrop

### Step 20: Calibration (if required)

1. **Sensor Calibration**:
   - Some sensors may require baseline calibration
   - Follow firmware instructions for calibration
   - Calibrate in clean air environment

2. **LED Calibration**:
   - Verify color accuracy
   - Adjust if necessary (via firmware)

---

## Troubleshooting

### Common Issues and Solutions

#### Issue 1: Device Does Not Power On

**Symptoms**: No LEDs, no response when USB connected

Short Circuit Detection - Teardrop

**Possible Causes**:
- Battery not connected or incorrectly connected
- Short circuit on PCB
- Faulty power management IC

**Solutions**:
1. Check battery connection and polarity
2. Verify no short circuits with multimeter
3. Check U3 and U4 are properly installed
4. Verify battery voltage (should be 3.7V)

#### Issue 2: LEDs Do Not Light

**Symptoms**: Device powers on but LEDs remain off

LED Not Working - Teardrop

**Possible Causes**:
- LEDs installed with incorrect polarity
- Faulty LED connections
- Firmware issue
- LEDs not visible through teardrop enclosure openings

**Solutions**:
1. Verify LED polarity matches PCB markings
2. Check LED solder joints
3. Test LEDs individually with multimeter
4. Verify firmware is correctly uploaded
5. Check that LEDs align with teardrop enclosure openings

Orientation Errors - Teardrop

#### Issue 3: Sensor Not Responding

**Symptoms**: LEDs show same color regardless of air quality

Sensor Vent Blockage - Teardrop

**Possible Causes**:
- Sensor not properly connected
- I2C communication issue
- Sensor blocked or damaged
- Sensor vents blocked by teardrop enclosure

**Solutions**:
1. Verify sensor is properly soldered
2. Check I2C bus connections (SDA, SCL)
3. Ensure sensor vents are not blocked by teardrop enclosure
4. Verify air flow path through teardrop enclosure openings
5. Test sensor with multimeter (check power pins)

#### Issue 4: Battery Not Charging

**Symptoms**: Device works but battery does not charge via USB

USB-C Connection Issues - Teardrop

**Possible Causes**:
- USB-C connector not properly installed
- Charge controller (U3) issue
- Battery protection circuit triggered
- USB-C connector not accessible through teardrop enclosure side opening

**Solutions**:
1. Verify USB-C connector is properly soldered
2. Check U3 installation and orientation
3. Test USB-C connection with multimeter
4. Verify USB-C connector aligns with teardrop enclosure side opening
5. Verify battery protection circuit is functioning

Battery Connection Problems - Teardrop

#### Issue 5: Device Overheats

**Symptoms**: Device becomes hot during operation

**Possible Causes**:
- Short circuit
- Faulty component
- Overcurrent condition

**Solutions**:
1. **IMMEDIATELY DISCONNECT POWER**
2. Check for short circuits
3. Verify all components are correct values
4. Check for damaged components

#### Issue 6: Teardrop Enclosure Does Not Close Properly

**Symptoms**: Teardrop enclosure halves do not fit together

**Possible Causes**:
- Components too tall
- PCB not properly seated in teardrop cavity
- Enclosure printing defects
- Circular PCB not fitting properly in teardrop shape

**Solutions**:
1. Verify all components are properly seated on PCB
2. Check PCB mounting and spacer height
3. Verify circular PCB fits within teardrop cavity (1-2mm clearance)
4. Verify 3D printed teardrop parts match specifications
5. Lightly sand teardrop enclosure if needed, especially curved areas

---

## Final Verification

### Step 21: Complete System Check

Perform final verification:

- [ ] Device powers on successfully
- [ ] LEDs display correct colors for air quality
- [ ] Sensor responds to air quality changes
- [ ] Audio alerts function properly
- [ ] Battery charges via USB-C through side opening
- [ ] Battery provides 16+ hours of operation
- [ ] Teardrop enclosure is secure and properly closed
- [ ] All openings (USB-C, sensor vents, side slots) are clear
- [ ] Necklace chain is properly attached at top
- [ ] Device is comfortable to wear
- [ ] Teardrop shape is aesthetically pleasing
- [ ] No unusual heat or behavior
- [ ] Firmware functions as expected

### Step 22: Documentation

1. **Record Serial Number** (if applicable)
2. **Note Any Modifications** made during assembly
3. **Document Calibration Values** (if calibrated)
4. **Keep Assembly Notes** for future reference

---

## Maintenance and Care

### Regular Maintenance

1. **Cleaning**:
   - Clean sensor vents periodically (ensure teardrop enclosure vents are clear)
   - Wipe teardrop enclosure with soft cloth
   - Avoid harsh chemicals

2. **Battery Care**:
   - Charge battery regularly
   - Avoid complete discharge
   - Store in cool, dry place

3. **Inspection**:
   - Periodically check for damage
   - Verify all functions still work
   - Check battery health
   - Inspect teardrop enclosure for cracks or wear

### Storage

- Store device in protective case
- Keep battery charged (50-80% for long-term storage)
- Avoid extreme temperatures
- Protect from moisture

---

## Support and Resources

### Additional Resources

- **Schematic Diagrams**: Available in project repository
- **Firmware Code**: Available in project repository
- **3D Model Files**: STL files for teardrop enclosure printing
- **Community Forums**: [Link to project discussion forum]

### Getting Help

If you encounter issues not covered in this guide:

1. Check troubleshooting section
2. Review schematic and PCB layout
3. Consult project documentation
4. Post questions in project forum
5. Contact project maintainers

---

## Appendix

### A. Component Datasheets

Key component datasheets for reference:
- STM32U083KCU6: [STMicroelectronics website]
- SGP40: [Sensirion website]
- MCP73832: [Microchip website]
- ADP150: [Analog Devices website]

### B. Tool Recommendations

Recommended tools for best results:
- Hakko FX-888D soldering station
- Weller WES51 (alternative)
- Kester 44 rosin core solder
- Chemtronics solder wick

### C. Additional Notes

- Assembly time may vary based on experience level
- First-time builders should allow extra time
- Practice soldering on scrap PCB if new to SMD work
- Take breaks to avoid fatigue and mistakes
- **Teardrop Enclosure Note**: The circular PCB (32.5mm diameter) fits within the teardrop-shaped enclosure cavity. Ensure proper clearance (1-2mm minimum) on all sides when placing PCB in teardrop enclosure.

---

**Document Control:**
- Prepared by: ProtoAI Design System
- Reviewed by: [To be assigned]
- Approved by: [To be assigned]
- Next Review Date: [To be determined]

**Revision History:**
- v1.0 (2025-12-06): Initial release - Teardrop Casing Variant

---

**End of Assembly Instructions**

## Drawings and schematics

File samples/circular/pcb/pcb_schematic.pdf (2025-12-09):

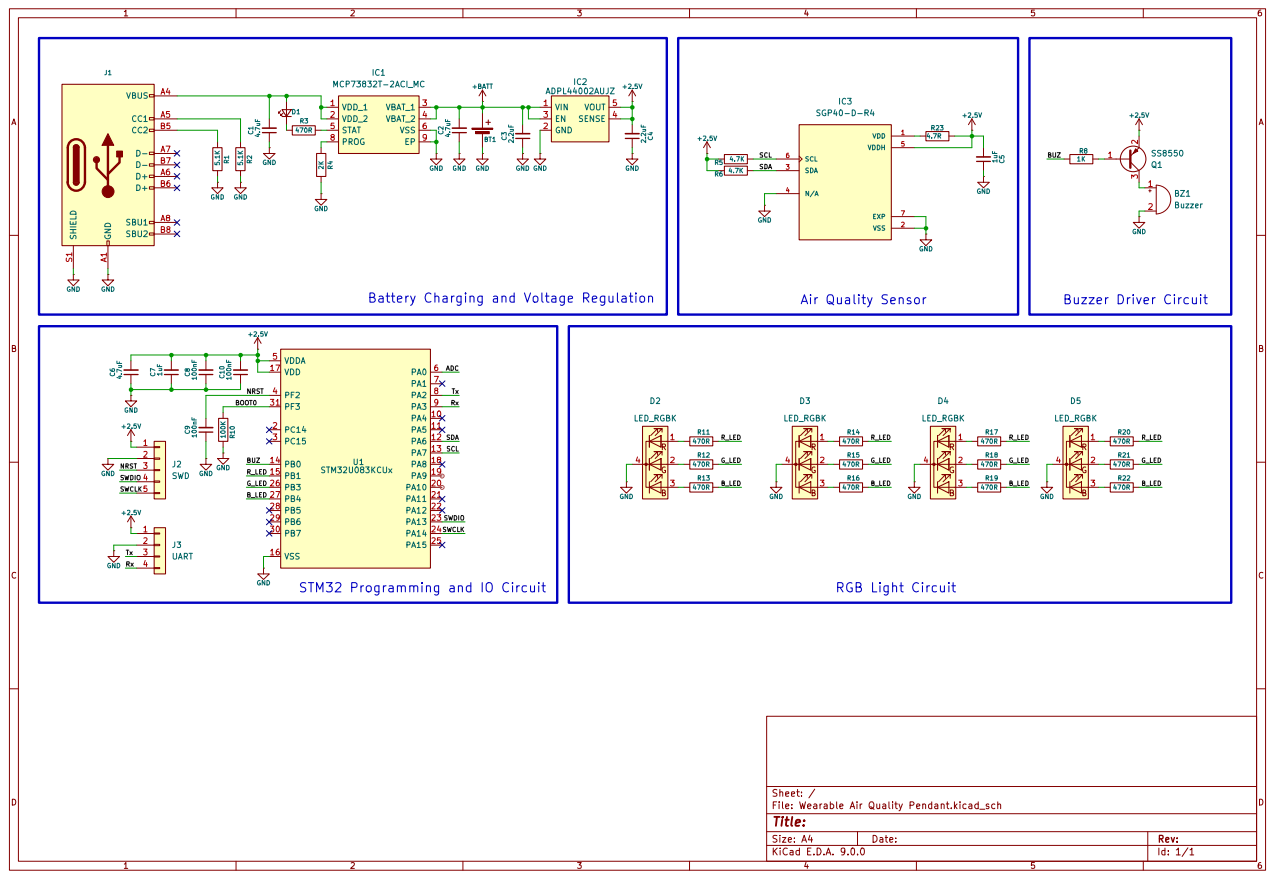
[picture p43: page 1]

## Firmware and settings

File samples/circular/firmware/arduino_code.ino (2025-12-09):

/*
  =======================================================================
  Project: Air Quality Monitor with TVOC Index using SGP40 Sensor

  Features:
  - Reads Total Volatile Organic Compounds (TVOC) index from SGP40 sensor
  - Indicates air quality using LEDs (Red, Green) with smooth fading effect
  - Plays RTTTL tone alerts for different air quality levels via buzzer
  - Displays TVOC values via LPUART serial (PA2, PA3)
  - Shows error states with visual (LED) and audible (buzzer) indication

  Working:
  - SGP40 sensor periodically reads TVOC index
  - Based on the index value, system classifies air as:
      0–200   → Good (Soft tone, Green LED)
      201–300 → Warning (Warn tone, Yellow LED)
      301–500 → Alarm (Alarm tone, Red LED)
  - If TVOC exceeds 500 or sensor fails, Error tone & Red LED flash
  - Scheduler ensures non-blocking periodic sensor read, LED updates, and sound
  =======================================================================
*/

#include <DFRobot_SGP40.h> // need to install
#include <HardwareSerial.h>
#include <Arduino.h>
#include <PlayRtttl.hpp> // need to install
#include <ptScheduler.h> // need to install

// LED and Buzzer pin definitions
#define RED_PIN PB3
#define GREEN_PIN PB4
#define BUZZER_PIN PB0

// Define serial on PA3 (RX) and PA2 (TX)
HardwareSerial MyLPUART1(PA3, PA2);

// Create SGP40 sensor object
DFRobot_SGP40 mySgp40;

// Variables for tone request and fading effect
int tvoc = 0;
int toneRequest = -1;
int fadeStep = 0;

// Time tracking variables for non-blocking operations
unsigned long prevLedTime = 0;
unsigned long prevToneTime = 0;

// Define RTTTL tone melodies
const char softTone[] = "Soft:d=8,o=5,b=100:g";
const char warnTone[] = "Warn:d=4,o=5,b=120:c,e,g";
const char alarmTone[] = "Alarm:d=16,o=5,b=180:c6,c6,c6";
const char startTone[] = "Start:d=8,o=6,b=120:c,e,g";
const char errorTone[] = "Error:d=4,o=5,b=160:c,c,r,c";

// Enum to associate tone types with time intervals
enum ToneType {
  TONE_SOFT = 5000,
  TONE_WARN = 2000,
  TONE_ALARM = 500,
  TONE_START = 1000,
  TONE_ERROR = 200
};

// Task scheduler for non-blocking periodic functions
ptScheduler readSensorTask(PT_TIME_1S);   // Sensor reading every 1 second
ptScheduler lightTask(PT_TIME_100MS);     // LED update task
ptScheduler soundTask(PT_TIME_100MS);     // Buzzer task

// Function declarations
void playTone(ToneType tone);
void updateLedFade(ToneType tone);
void showErrorState();
void readAndEvaluateAir();

void setup() {
  MyLPUART1.begin(115200);

  // Initialize output pins
  pinMode(RED_PIN, OUTPUT);
  pinMode(GREEN_PIN, OUTPUT);
  pinMode(BUZZER_PIN, OUTPUT);

  MyLPUART1.println("sgp40 is starting, the reading can be taken after 10 seconds...");

  // Startup indication
  updateLedFade(TONE_START);
  playTone(TONE_START);

  // Initialize sensor
  if (!mySgp40.begin(10000)) {
    MyLPUART1.println("Failed to init chip. Please check connection.");
    showErrorState();
    while (true);  // Stop execution on failure
  }

  MyLPUART1.println("sgp40 initialized successfully!");
}

void loop() {
  // Periodically read sensor
  if (readSensorTask.call()) {
    readAndEvaluateAir();
  }

  // Update LED fading effect based on tone
  if (lightTask.call() && toneRequest != -1) {
    updateLedFade((ToneType)toneRequest);
  }

  // Play tone based on tone request
  if (soundTask.call() && toneRequest != -1 && toneRequest != TONE_SOFT) {
    playTone((ToneType)toneRequest);
  }
}

// Reads TVOC value and determines air quality level
void readAndEvaluateAir() {
  tvoc = mySgp40.getVoclndex();

  MyLPUART1.print("vocIndex = ");
  MyLPUART1.println(tvoc);

  if (tvoc <= 200) {
    toneRequest = TONE_SOFT;
  } else if (tvoc <= 300) {
    toneRequest = TONE_WARN;
  } else if (tvoc <= 500) {
    toneRequest = TONE_ALARM;
  } else {
    MyLPUART1.println("Invalid TVOC value.");
    showErrorState();
  }
}

// Smooth LED fading based on tone type
void updateLedFade(ToneType tone) {
  static const int maxBrightness = 255;
  static const int fadeSpeed = 5;
  static const int fadeDelay = 10;

  unsigned long currentMillis = millis();
  if (currentMillis - prevToneTime < tone) return;
  prevToneTime = currentMillis;

  int redTarget = 0, greenTarget = 0;

  // Set target brightness levels based on tone
  switch (tone) {
    case TONE_SOFT: greenTarget = maxBrightness; break;                  // Green only
    case TONE_WARN: redTarget = greenTarget = maxBrightness; break;     // Yellow (Red + Green)
    case TONE_ALARM:
    case TONE_ERROR: redTarget = maxBrightness; break;                  // Red only
    default: break;
  }

  // Fade in
  for (int brightness = 0; brightness <= 255; brightness += fadeSpeed) {
    analogWrite(RED_PIN, (brightness * redTarget) / 255);
    analogWrite(GREEN_PIN, (brightness * greenTarget) / 255);
    delay(fadeDelay);
  }

  // Fade out
  for (int brightness = 255; brightness >= 0; brightness -= fadeSpeed) {
    analogWrite(RED_PIN, (brightness * redTarget) / 255);
    analogWrite(GREEN_PIN, (brightness * greenTarget) / 255);
    delay(fadeDelay);
  }

  // Reset if loop exceeds max fade cycle
  fadeStep += fadeSpeed;
  if (fadeStep > 510) {
    analogWrite(RED_PIN, 0);
    analogWrite(GREEN_PIN, 0);
  }
}

// Play a tone melody corresponding to the tone type
void playTone(ToneType tone) {
  unsigned long currentMillis = millis();
  if (currentMillis - prevLedTime < tone) return;
  prevLedTime = currentMillis;

  switch (tone) {
    case TONE_SOFT:  playRtttlBlockingPGM(BUZZER_PIN, softTone); break;
    case TONE_WARN:  playRtttlBlockingPGM(BUZZER_PIN, warnTone); break;
    case TONE_ALARM: playRtttlBlockingPGM(BUZZER_PIN, alarmTone); break;
    case TONE_START: playRtttlBlockingPGM(BUZZER_PIN, startTone); break;
    case TONE_ERROR: playRtttlBlockingPGM(BUZZER_PIN, errorTone); break;
  }
}

// Show error condition using LED and buzzer
void showErrorState() {
  toneRequest = TONE_ERROR;
  soundTask.enable();
}

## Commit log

2025-12-09 Initial commit: Open source sample assembly instructions for Wearable Air Quality Pendant
    - Add complete assembly instructions for circular and teardrop design variants
    - Include 3D models (STL files), PCB schematics, Gerber files, and firmware
    - Add comprehensive documentation with step-by-step guides and images
    - Include MIT license and proper attribution to Circuit-Digest
    - Add README with ProtoAI platform overview and hackathon submission details
    [pendant-bottom-circular.stl, pendant-top-circular.stl]
2025-12-09 Fix image paths in assembly instructions
    - Update all image references from 'assembly-images/' to 'images/'
    - Fixes broken image links in both circular and teardrop variants
    - Ensures images display correctly in markdown viewers
2025-12-09 Fix image paths in Testing and Calibration sections
    - Remove incorrect 'circular-original' subdirectory from testing image paths
    - Remove incorrect 'circular-original' subdirectory from troubleshooting image paths
    - All images in 04-testing and 05-troubleshooting now correctly reference images/ directory
    - Completes the image path fix started in previous commit
